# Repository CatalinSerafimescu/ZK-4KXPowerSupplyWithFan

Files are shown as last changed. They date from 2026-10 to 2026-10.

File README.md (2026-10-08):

# ZK-4KX Enhanced Power Supply — temperature-controlled fan

A bench power supply built around the cheap **ZK-4KX buck-boost panel module** (IN 5–30 V, OUT 0.5–30 V,
[datasheet](https://www.laskakit.cz/user/related_files/zk-4kx_english.pdf)), with a 3D-printed case and a small
add-on board that runs a cooling fan **only when the module gets warm**, faster as it gets hotter.
Everything runs from the same DC input (9 V / 2 A adapter tested, up to ~28 V supported).

| Finished supply | Inside |
|---|---|
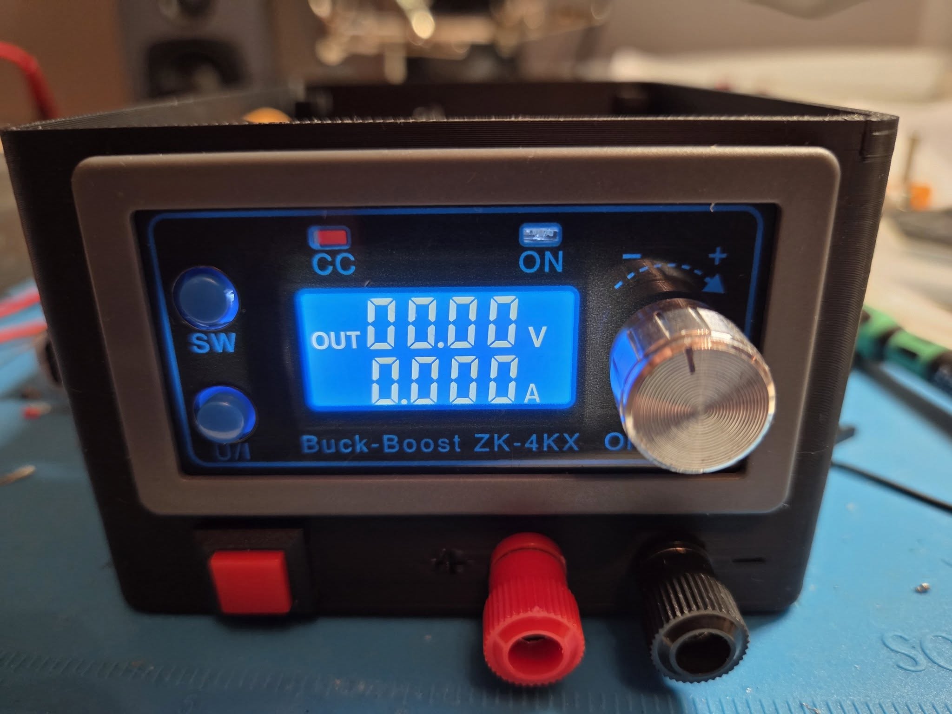
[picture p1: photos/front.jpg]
Front
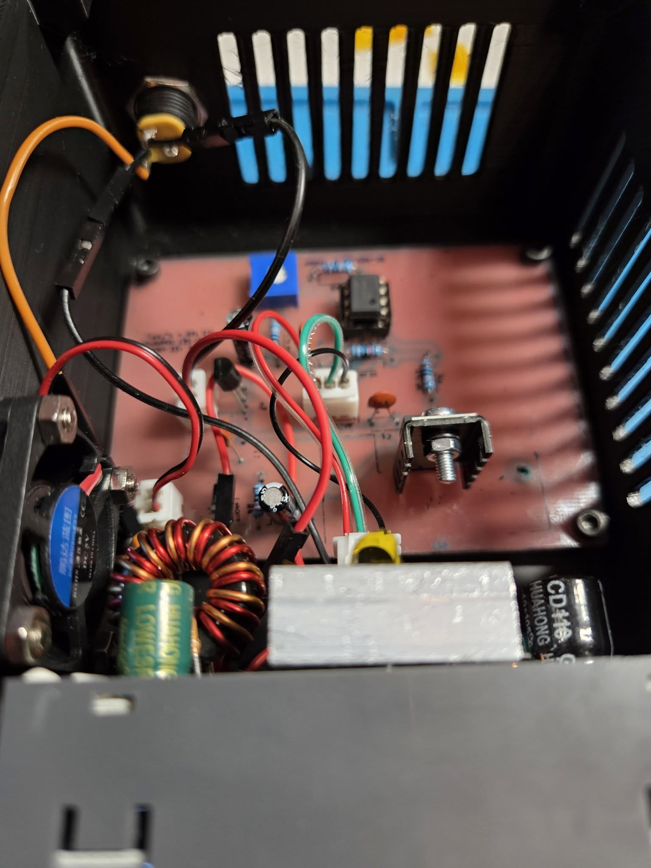
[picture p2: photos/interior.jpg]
Interior
|  |  |

- Single-sided PCB, 90 × 66 mm, designed for **home etching** (toner transfer, no vias, no jumpers) — Gerbers included if you'd rather order it.
- Through-hole parts only: LM35, LM358, LM317, 78L05, one trimmer.
- Fan **off** below a start temperature you set with the trimmer (~15 … 52 °C), full speed ~18 °C above it.
- Fan voltage can never exceed 5 V, whatever the input voltage or faults.
- Printable case, 98 × 128 × 68 mm, magnetic lid, no supports.

**Build guide:** [instruction.md](instruction.md) — parts, etching, assembly, wiring, first power-up, calibration, troubleshooting.

## Downloads

| What | File |
|---|---|
| Bill of materials | [bom.md](bom.md) |
| Schematic | [KiCAD/SursaTensiune_sch.pdf](KiCAD/SursaTensiune_sch.pdf) |
| PCB print for toner transfer (+ solder mask film), A4, print at 100 % | [KiCAD/toner_B.Cu_1to1.pdf](KiCAD/toner_B.Cu_1to1.pdf) |
| Gerbers + drill files for ordering the PCB | [KiCAD/gerber/SursaTensiune_gerbers.zip](KiCAD/gerber/SursaTensiune_gerbers.zip) |
| Assembly BOM in PCBWay's format | [KiCAD/SursaTensiune_BOM_PCBWay.xlsx](KiCAD/SursaTensiune_BOM_PCBWay.xlsx) |
| Enclosure, printable | [Enclosure_base.3mf](mechanical/enclosure/Enclosure_base.3mf), [Enclosure_cover.3mf](mechanical/enclosure/Enclosure_cover.3mf) (print orientation; STL and STEP next to them), [Bambu Studio project for the A1](mechanical/enclosure/Enclosure_A1_project.3mf) — see [enclosure notes](mechanical/enclosure/README.md) |
| Solder-mask jig, printable (optional) | [Mask_jig.stl](mechanical/mask_jig/Mask_jig.stl) — see [jig notes](mechanical/mask_jig/README.md) |
| KiCad 10 project | [KiCAD/](KiCAD/) — see [PCB_info.md](KiCAD/PCB_info.md) |

## Build photos

| Design | | |
|---|---|---|
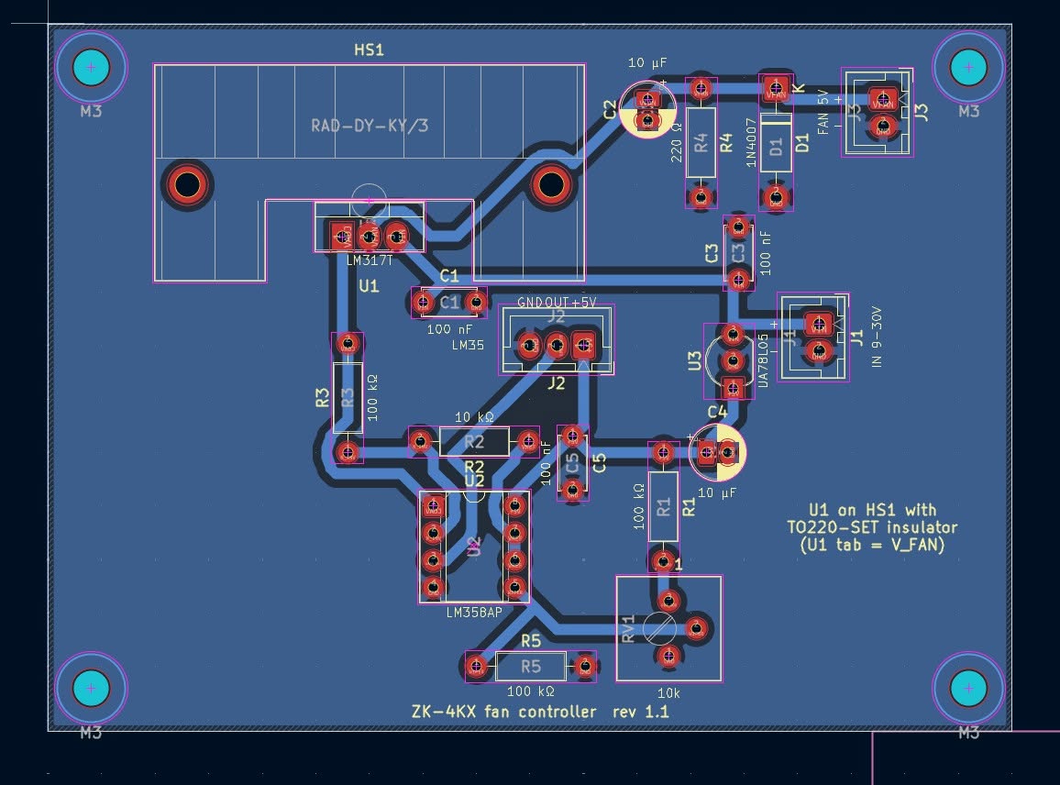
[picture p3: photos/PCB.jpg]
PCB layout
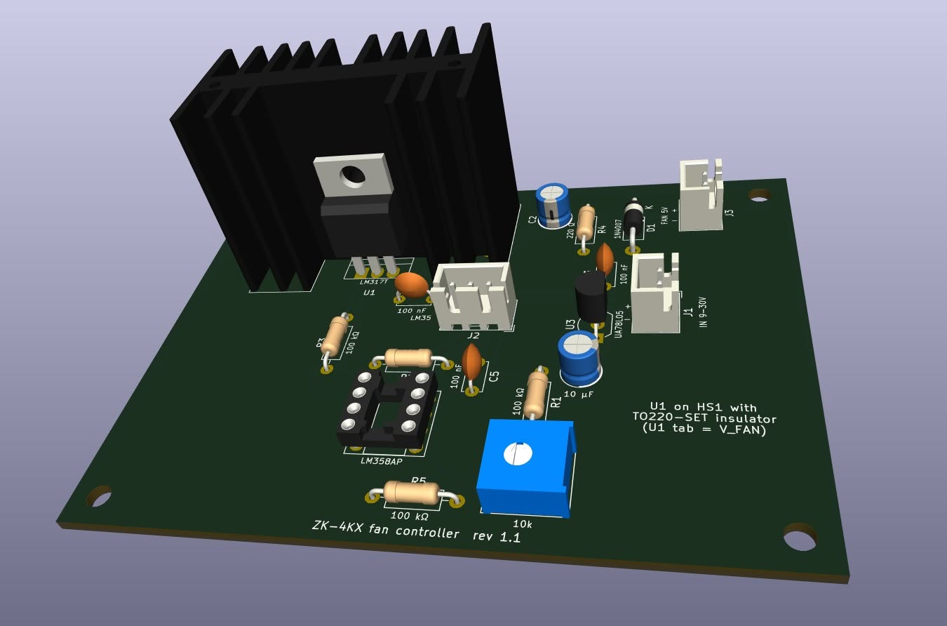
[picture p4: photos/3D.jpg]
3D view
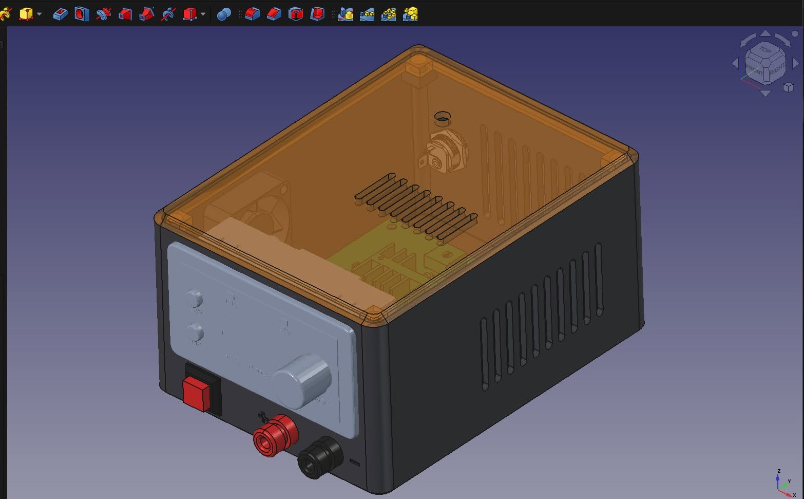
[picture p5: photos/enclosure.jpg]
Enclosure model
|  |  |  |
| PCB layout (KiCad) | 3D view | Enclosure (FreeCAD) |

| Making the board | | |
|---|---|---|
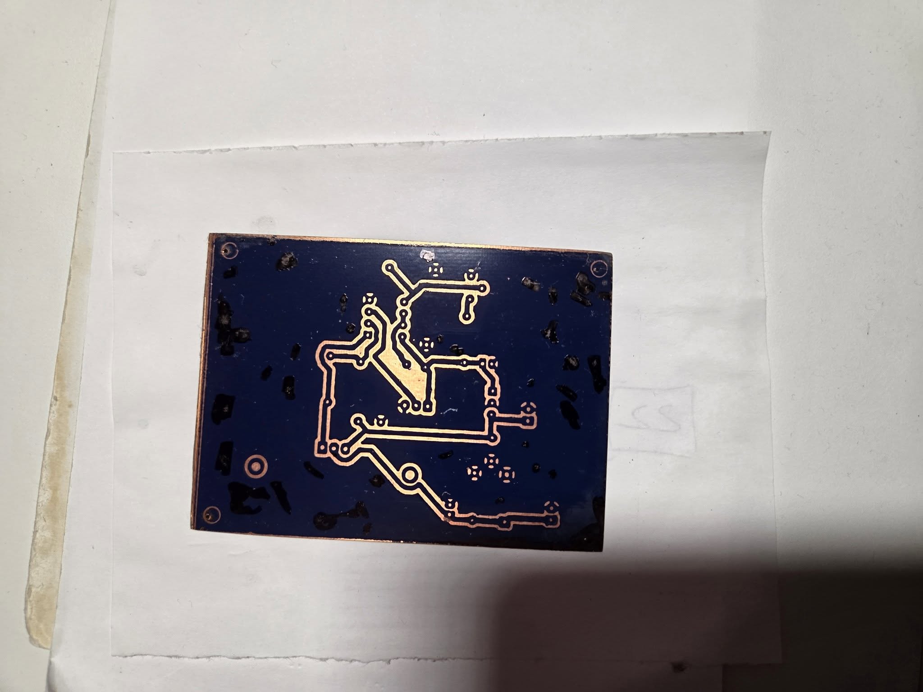
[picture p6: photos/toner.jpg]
Toner transfer
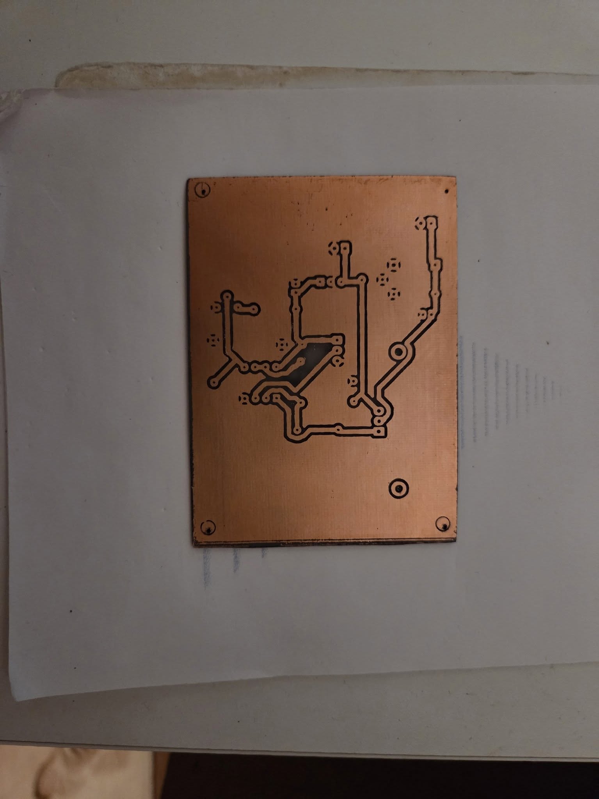
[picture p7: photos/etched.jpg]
Etched
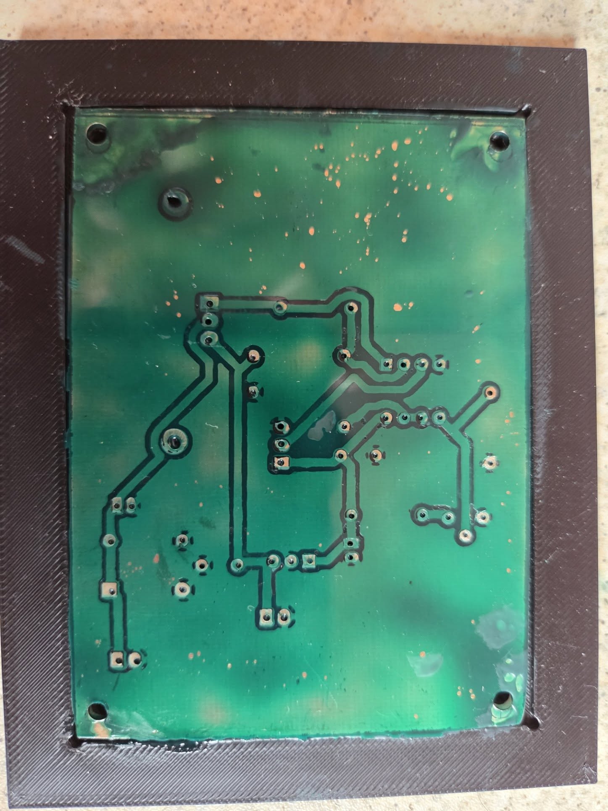
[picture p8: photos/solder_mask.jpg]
Solder mask
|  |  |  |
| Toner transferred | Etched | UV solder mask, board in the printed jig |
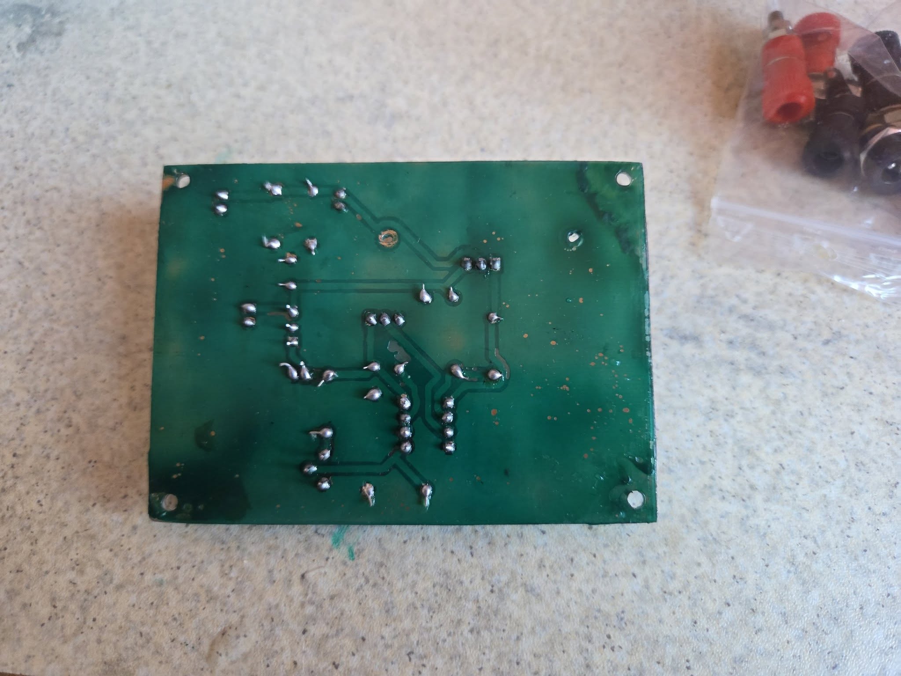
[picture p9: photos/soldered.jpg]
Soldered, bottom
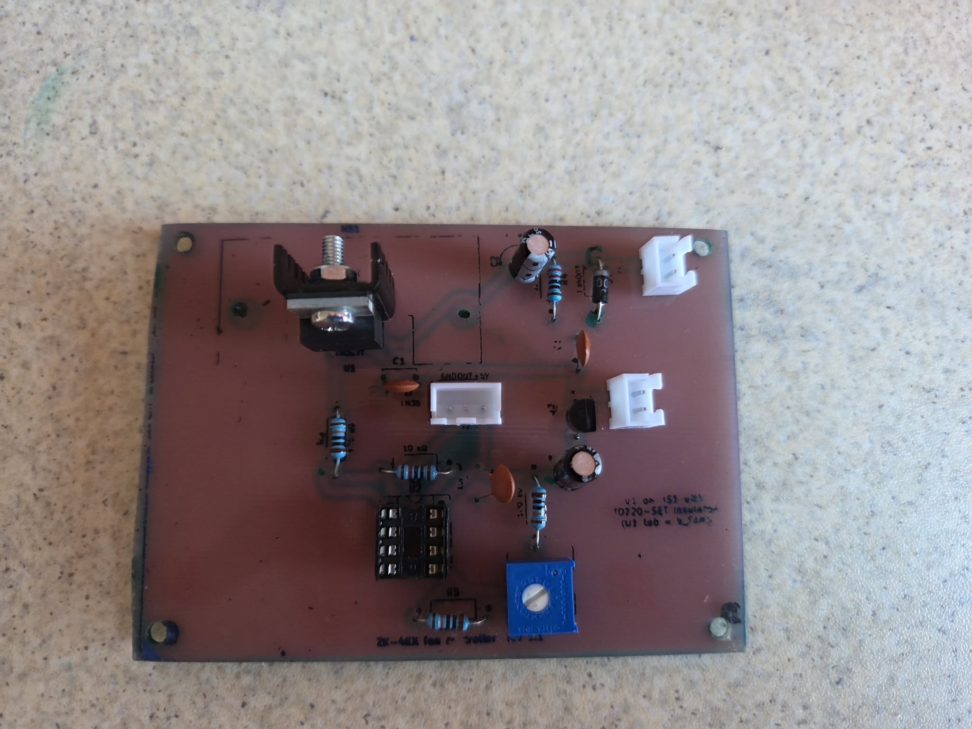
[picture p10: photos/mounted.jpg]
Assembled
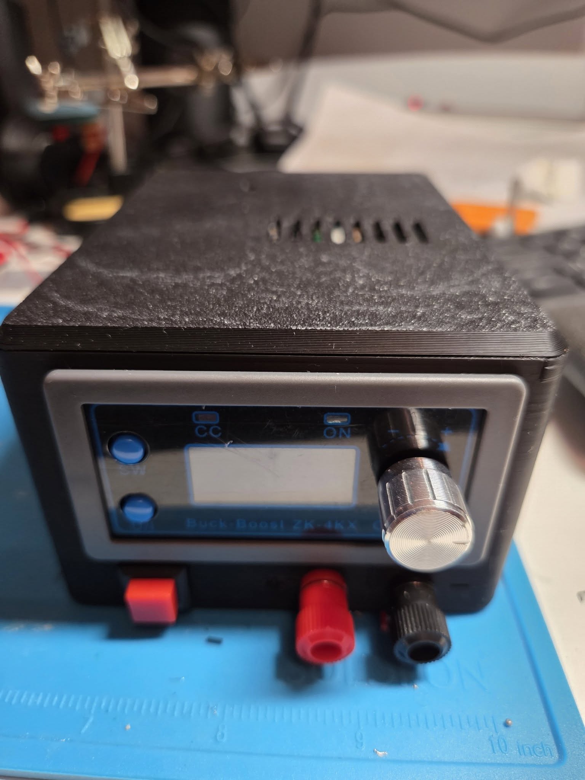
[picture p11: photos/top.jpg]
Top
|  |  |  |
| Soldered (bottom) | Assembled board | Closed case, vents on top |

## How it works

| Block | Parts | Function |
|---|---|---|
| 5 V aux | U3 78L05, C3, C4, C5 | Supplies U2 and the LM35 |
| Start temperature | R1, RV1, R5, U2B | V_REF = 0 … 0.42 V, buffered |
| Amplifier | U4 LM35, U2A, R2, R3 | V_ADJ = 11·V_LM35 − 10·V_REF (clamped 0 … ~3.5 V by the 5 V supply) |
| Fan supply | U1 LM317, C1, C2, R4, D1 | V_FAN = V_ADJ + 1.25 V → 1.25 V (off) … 4.75 V (full) |

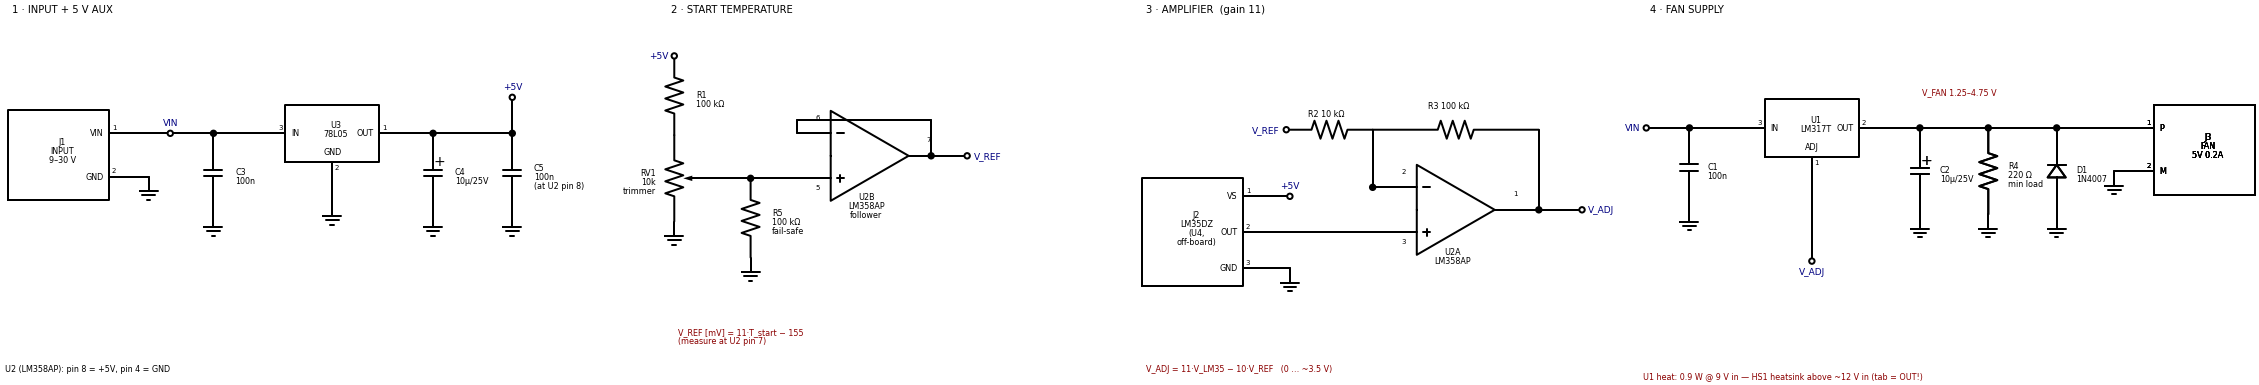
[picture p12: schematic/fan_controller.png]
Schematic


- Fan: Raspberry Pi type 30×30×10 mm, 5 V / 0.2 A, 2-wire. The LM35 sits on the ZK-4KX heatsink.
- Fan starts (≈ 2.8 V, measured) at **T_start**, reaches full speed at **T_start + ~18 °C**.
- T_start range with RV1: **~15 … 52 °C**.
- **Calibration:** measure U2 pin 7 → **V_REF [mV] = 11 · T_start − 155** (e.g. 285 mV → 40 °C).
- Narrower ramp (~9.5 °C): R2 = 5.1 kΩ.
- Fail-safes: pot wiper open → fan runs from ~17 °C (R5); LM35 disconnected → fan full speed.
- U1 dissipation: 0.9 W @ 9 V in, 5.3 W @ 30 V in (HS1 + insulating kit; tab = OUT).
- Simulated in both ngspice and LTspice (nominal, trimmer extremes, input sweep, power-up, open wiper/sensor,
  op-amp offset worst cases) — see [simulation/README.md](simulation/README.md).

## Repository layout

| Path | Content |
|---|---|
| `bom.py` → `bom.md` | BOM, single source of truth. Run `python bom.py`. |
| `instruction.md` | Build guide |
| `schematic/` | Schematic image (schemdraw, `gen_schematic.py`), labels from `bom.py` |
| `KiCAD/` | KiCad 10 project, generator scripts (`gen/`), print PDF, Gerbers. See `KiCAD/PCB_info.md`. |
| `simulation/` | Same scenarios in ngspice 46 and LTspice 26 |
| `mechanical/` | Enclosure and solder-mask jig (FreeCAD scripts, STEP, STL, 3MF), part models used for fit checks. See `mechanical/README.md`. |
| `photos/` | Build photos |

## Credits and third-party files

These files are not mine and keep their original terms (they are **not** covered by this project's licenses):

- `mechanical/stl/ZK-4KX Buck Boost Converter.STL` — by Legacy_Micro,
  [Printables 401707](https://www.printables.com/model/401707-basic-model-zk-4kx-buck-boost-converter), CC0.
- `mechanical/button/DS-431_square_push_button_red.step` — from
  [GrabCAD](https://grabcad.com/cads/files/da40e36f2500ba5d71d7cf6f930e5d73/original.step).
- `mechanical/fan/Fan_30x30x10_5V_2pin.step` — modified from A. Kirchner's 30×30×8 fan model,
  [GrabCAD](https://grabcad.com/library/fan-30x30x8mm-5v-2-pin-1).
- `mechanical/dc_jack/DC_jack_5.5x2.1_panel_10A.step` (+ 2 renders) — from
  [GrabCAD](https://grabcad.com/library/power-jack-socket-5-5-x-2-1-mm-10a-dc-1).
- `mechanical/heatsink/*.jpg` — TME product images of the Stonecold RAD-DY-KY heatsink.
- ZK-4KX datasheet and heatsink datasheet are linked, not included.

**Not included** (licences don't allow redistribution) — download them and save under these names if you need them:

| File | What | Where to get it | Needed for |
|---|---|---|---|
| `KiCAD/vendor/3386P-1-103LF.stp` | Bourns 3386P trimmer 3D model | [SamacSys / Component Search Engine](https://componentsearchengine.com) | RV1 3D body in KiCad |
| `mechanical/trimmer/3386P-1-103LF.stp` | same model (copy) | as above | reference only |
| `mechanical/banana/930176100.stp` | Hirschmann 930176100 banana socket | [SamacSys / Component Search Engine](https://componentsearchengine.com) | `mechanical/enclosure/assembly.py` |
| `simulation/vendor/onsemi_LM358.mod` | onsemi LM358 SPICE model | [onsemi models](https://onsemi.com/support/design-resources/models?rpn=LM358) | `run_sim.py --vendor` |
| `simulation/vendor/LT317A.sub` | ADI LT317A SPICE model | bundled with LTspice (`lib.zip` → `lib/sub/LT317A.sub`) | `run_sim.py --vendor` |

Everything else (schematic, PCB, Gerbers, enclosure, behavioral simulations) works without them.

## Support

If this project saved you some time, you can buy me a coffee (via PayPal):

<a href="https://www.paypal.com/donate/?hosted_button_id=YSV46KQ6EUAEE">Buy me a coffee</a>

## License

Copyright © 2026 Catalin Serafimescu. See [LICENSE](LICENSE):

- Hardware (KiCad project, Gerbers, enclosure and jig) — [CERN-OHL-S-2.0](LICENSES/CERN-OHL-S-2.0.txt)
- Software (Python scripts, SPICE files) — [MIT](LICENSES/MIT.txt)
- Documentation and images — [CC BY-SA 4.0](LICENSES/CC-BY-SA-4.0.txt)

Mains is not involved, but you are working with up to 30 V / 4 A — build and use at your own risk.

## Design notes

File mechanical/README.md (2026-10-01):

# Mechanical files

| File | What |
|---|---|
| Heatsink datasheet | Stonecold RAD-DY-KY profile drawing (40×20 mm, 4 mm base, pins at 34 mm, M3, 6.9 K/W for L = 30 mm) — not included, see [TME](https://www.tme.eu/en/katalog/?search=RAD-DY-KY%2F3) |
| `heatsink/RAD-DY-KY.jpg`, `RAD-DY-KY_top.jpg` | TME photo and profile — source for the KiCad footprint (`../KiCAD/gen/gen_heatsink.py`) |
| `stl/ZK-4KX Buck Boost Converter.STL` | ZK-4KX panel module, 79 × 54 × 42.5 mm — by Legacy_Micro, [Printables 401707](https://www.printables.com/model/401707-basic-model-zk-4kx-buck-boost-converter), CC0 |
| `pcb/SursaTensiune_board.step` | Whole fan-controller board with all parts, **including the heatsink** (KiCad export, solids — best for FreeCAD) |
| `pcb/SursaTensiune_board.stl` | Same board as a mesh — 90 × 66 × 39.7 mm |
| `trimmer/3386P-1-103LF.stp` | Bourns 3386P trimmer — **not included** (SamacSys licence: no redistribution). Download from [SamacSys / Component Search Engine](https://componentsearchengine.com), part 3386P-1-103LF. |
| `banana/930176100.stp` | 4 mm banana panel socket (Hirschmann 930176100), ≈ 33 × 15 × 10 mm — **not included** (SamacSys licence: no redistribution). Download from [SamacSys / Component Search Engine](https://componentsearchengine.com); needed by `enclosure/assembly.py`. Stand-in for J6/J7 — the Sigmanortec sockets may differ slightly, measure. |
| `dc_jack/DC_jack_5.5x2.1_panel_10A.step` (+ 2 renders) | Panel-mount DC jack 5.5×2.1 mm, 10 A — the one on the case (J5). ≈ 14 × 24 × 20 mm, threaded body + nut, 3 solder tabs. From [GrabCAD](https://grabcad.com/library/power-jack-socket-5-5-x-2-1-mm-10a-dc-1). |
| `button/DS-431_square_push_button_red.step` | Power switch SW1: DS-431 latching push switch, 14 × 14 mm rim, 11.5 × 10.8 mm body with snap clips, 20 mm deep incl. the 2 solder tabs |
| `fan/Fan_30x30x10_5V_2pin.step` (+ `.png`) | 30×30×**10** mm 2-pin 5 V fan (M1). Made in FreeCAD from A. Kirchner's 30×30×8 model ([GrabCAD](https://grabcad.com/library/fan-30x30x8mm-5v-2-pin-1)): frame cut at mid-height, top half raised 2 mm and the gap filled (valid solid, exact planes/cylinders, holes unchanged); rotor unchanged, centred. The original rotor had broken face trims (drawn as an endless tube along the fan axis, reappearing after every STEP round trip), so it was replaced by a clean hub + 7 pitched blades. 203 KB, opens in < 1 s. FreeCAD version: `stl/Fan10.FCStd`. |

The fan mount STL that came with the ZK-4KX model is not used.

Board exports are regenerated with `kicad-cli pcb export step|stl --subst-models` after PCB changes.

KiCad cannot use STL as a 3D model (STEP/VRML only); the fan and ZK-4KX are off-board, so these models are
for the enclosure design. Heatsink 3D: `../KiCAD/SursaTensiune.3dshapes/RAD-DY-KY-3.step` — black solid with rounded fins, pin grooves and the
M3 hole, built in FreeCAD by `../KiCAD/gen/gen_heatsink_step.py` (run it inside the FreeCAD GUI to keep the colours).
Enclosure: see [`enclosure/`](enclosure/README.md). Solder-mask jig (holds the PCB flush under the mask film):
[`mask_jig/`](mask_jig/README.md).

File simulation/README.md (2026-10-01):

# Simulation — fan temperature controller

The same 11 scenarios, run in two simulators:

| Folder | Simulator | Results |
|---|---|---|
| [`ngspice/`](ngspice/README.md) | ngspice 46 (`ngspice_con.exe -b`) | [RESULTS.md](ngspice/results/RESULTS.md) |
| [`ltspice/`](ltspice/README.md) | LTspice 26 (`LTspice.exe -b`) | [RESULTS.md](ltspice/results/RESULTS.md), vendor models: [RESULTS.md](ltspice/results_vendor/RESULTS.md) |

[`scenarios.py`](scenarios.py) is shared: stimuli, parameters and pass/fail assertions are defined once.
Each folder has its own netlist template and `models.lib` (identical behavioral models today).
[`vendor/`](vendor/README.md) holds manufacturer models (onsemi LM358, ADI LT317A), used by `ltspice/run_sim.py --vendor`.

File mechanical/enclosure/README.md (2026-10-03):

# Enclosure — 3D-printable case

Parametric FreeCAD script: [`gen_enclosure.py`](gen_enclosure.py) (all dimensions at the top).
[`assembly.py`](assembly.py) places the real part models (ZK-4KX, board, fan, banana sockets, power switch, DC jack) for checking;
the result is saved as [`Enclosure_assembly.FCStd`](Enclosure_assembly.FCStd).

Outside **98 W × 128 D × 68 H mm**. Two printed parts. The `.3mf` files are already in print orientation (cover flipped,
both on the bed); the `.stl` files are in assembly position.

**Bambu Studio project:** [`Enclosure_A1_project.3mf`](Enclosure_A1_project.3mf) — Bambu Lab A1, 0.4 nozzle,
0.20mm Standard, Bambu PLA Basic, no supports; plate 1 = base (≈ 2 h 45 min), plate 2 = cover (≈ 45 min).
Made from the two `.3mf` files with the Bambu Studio CLI, using the system presets with their `inherits` chains
flattened first (the CLI doesn't resolve them and falls back to a 200 × 200 bed); then split into two plates
and renamed by hand. The plain `.3mf` files open in Bambu Studio with a "geometry only" notice — expected for
3MFs not made by Bambu Studio.

| Part | What | Print |
|---|---|---|
| `Enclosure_base` (.step / .stl / .3mf) | Open box: floor + all 4 walls, board standoffs, 4 corner magnet bosses | Floor down, no slicer supports (built-in breakaway pane in the ZK-4KX cutout, see below) |
| `Enclosure_cover` (.step / .stl / .3mf) | Top only (the chamfered cap, split at Z 65): lip inside the walls, 4 corner magnet blocks | **Upside down** (top on the bed), no supports |

Style: rounded vertical corners (R6), 45° chamfer on the top edges (3 mm), 1.2 mm chamfer on the bottom edges
(bed adhesion / elephant foot). Front and rear panels can be printed in a second colour.

## Layout
- **Front:** ZK-4KX on top (cutout 77.4 × 39.6, 6 mm wider than the datasheet so the side clips pass, panel thinned to **1.3 mm** around it — the clips grip 1.4 mm behind
  the bezel). **Below it, one row:** power switch SW1 (DS-431, 12.7 × 11.0 mm hole) on the left, then the banana
  sockets side by side, 19.05 mm apart (fits dual banana plugs), red **+** left, black **−** right (engraved beside them).
  Output leads leave the middle of the front, not the side — fine for right- and left-handed use.
- **Rear:** DC jack Ø12.2 (M12 body) on the left, labelled "9-30V"; exhaust slots.
- **Left side:** fan 30×30×10 on the full 2.4 mm wall (Ø28.5 grille, 4× Ø3.4 holes at 24 mm). Its axis is 11 mm
  behind the ZK-4KX rear heatsink centre, so that heatsink sits under the **blades** (an axial fan blows almost nothing
  behind its Ø17 hub) and the jet (Y 24–54) also reaches the front of the board heatsink (Y 47–67). Air then leaves
  through the right-side, rear and top vents — the board heatsink's fins run front-to-back, along that path.
- **Right side:** exhaust slots.
- **Top (cover):** vents above the board heatsink, **Ø5 hole above trimmer RV1** (set the start temperature with the lid on).
- **Inside:** fan board on 4 × 6 mm standoffs behind the ZK-4KX, rotated 180°, 1.5 mm from the left wall — its front
  edge runs under the fan (the parts there, J3 and C2, stay below it), J3 right under the fan.

## Assembly
| Joint | Hardware |
|---|---|
| Fan board → base | 4× **M3×10** from the top, M3 nuts pushed into the hex pockets under the floor |
| Cover → base | 4 pairs of **Ø5×3 neodymium magnets** (comp_193) in the corners; the lip inside the walls locates it |
| Fan → base | 4× **M3×16** + nuts through the 2.4 mm left wall |
| ZK-4KX | snaps into the front cutout from the front |
| Banana sockets, DC jack | their own nuts, from inside (lid off) |
| Power switch SW1 | snaps in from the front (wire it before, or push it out from inside to rewire) |

Order: ZK-4KX, banana sockets, switch, DC jack into the base → wire them → board on the standoffs → plug J1/J2 →
fan on the left wall → plug J3 → put the cover on (it snaps down on the magnets, lift to open). Stick-on rubber feet
recommended.

**Magnets:** pockets are Ø5.3 × 3.3 deep (0.3 mm glue room; the magnet ends 0.3 mm below the face). Glue them with
a drop of CA. Mind the polarity: snap each pair together, mark the two touching faces with a
marker, pull them apart, and glue each one with the marked face out (base magnet in its boss, partner in the cover
block above it). Boss tops sit 0.2 mm below the cover blocks, so the cover rests on
the wall rim, not on the magnets.

## Fit check (done in FreeCAD with the real models)
- No collisions between the base/cover and the board, fan, banana sockets, power switch or DC jack. The only
  overlaps are the switch's snap clips (0.6 mm wedges behind the panel edge — that is how it holds) and the LM317's
  uncut 3D-model leads (see below).
- ZK-4KX (STL mesh) clear of all walls and of the fan (closest ZK part 2.9 mm from the fan face — the fan follows
  the ZK-4KX heatsink height). Banana sockets ≥ 4.5 mm and the switch ≥ 2.7 mm below the ZK-4KX body.
- Board front edge under the fan: tallest part there (C2, J3) tops out at Z 17, fan bottom at Z 26.5.
- Cover lip (Z 61.5–65) and the corner magnet bosses (Z ≥ 49, 8 × 8 mm in the corners): clear of the ZK-4KX
  (body X 14.5–85.5, top Z 60.5; its clips reach X 11–89 only at Z 35–47), of the fan (top Z 57.8) and of the
  board (Y 43–109). No overlap between base and cover.
- Trimmer hole in the lid centred on RV1's adjuster (checked on the board STEP).
- Under the board: 6 mm standoffs. **Trim all leads to ≤ 3 mm** below the PCB (the KiCad LM317 model shows uncut
  leads that would touch the floor).

## Check before printing
- Banana sockets: the model is a stand-in (Hirschmann 930176100, M6) — measure your Sigmanortec sockets' thread.
- Power switch: hole 12.7 × 11.0 mm (DS-431 model 11.7, +1 mm after the first fit test; body 11.5 × 10.8, clips on the 11.5 sides);
  change `SW_CUT` if needed. The front panel is 2.4 mm there; the clips suit 1–3 mm panels.
- ZK-4KX clip grip (1.4 mm) is from the STL model; the panel is 1.3 mm there — if the clips don't catch, reduce `ZK_PANEL`.
- The 77 mm top edge of the ZK-4KX cutout is a print bridge. The base carries its own **breakaway window pane**
  there: a 0.8 mm plate flush with the front face, standing on 7 posts (0.8 × 0.6 × 0.6 mm) on the cutout's bottom
  edge, held by 3 sprues per side across a 0.5 mm gap, its top one layer (0.2 mm) below the edge. Tuned for
  **0.2 mm layers / 0.4 mm nozzle** (cutout edges, pane and sprues on the 0.2 mm grid; cutout Z 21.2 / 60.8).
  Slicer supports off. After printing, push the pane out from inside and trim the sprue nubs on the side edges
  flush (the ZK-4KX clips run along those edges). Other layer heights: set `PANE_GAP_Z` to one layer and keep the
  cutout edges on the layer grid.

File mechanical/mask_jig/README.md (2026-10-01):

# Solder-mask jig

`Mask_jig.step` / `.stl`, made by `gen_mask_jig.py` (run in the FreeCAD GUI). 110.8 × 86.8 × 4.4 mm, print
floor-down, no supports.

- **Pocket** 90.8 × 66.8 mm (0.4 mm per side around the 90 × 66 board), **1.4 mm deep**: a 1.5–1.6 mm board sits
  0.1–0.2 mm proud, so the film is pressed onto the board and then lies flat on the 10 mm frame. If your board
  is thinner than 1.4 mm, put a paper shim under it.
- **4 × Ø3.2 through holes** at the board's mounting holes (4 mm in from each corner) for registration pins —
  Ø3 drill-bit shanks or M3 screws pushed up from below.
- Corner reliefs (square board corners in an FDM pocket) and 2 × Ø12 holes to push the board out from below.

## Use (UV solder mask)
1. Etched board **drilled**, cleaned, copper side up in the pocket. Pins up through the mounting holes.
2. Film: the two B.Mask copies from page 3 of `KiCAD/toner_B.Cu_1to1.pdf`, stacked, **toner side down**. Punch/drill
   Ø3.2 through the 4 black corner dots (the mounting-hole openings) with the stack taped together.
   The mounting holes are symmetric, so the pins alone don't fix the orientation: check the two big HS1 dots and
   the pad rows line up with the board before the paste goes on.
3. Paste on the board, film down over the pins, squeegee from the centre outwards (excess goes into the gap and
   onto the frame). Tape the film edges to the frame.
4. Pull the pins out **downwards**, lay a sheet of glass on top for even pressure, expose. Ordinary picture-frame
   glass passes 395–405 nm LEDs well but cuts a lot at 365 nm — expose longer, or skip the glass with a 365 nm lamp.
5. Paste squeezed onto the frame cures there too: cover the frame with one layer of packing tape before step 3 and
   peel it off afterwards, so the frame stays flat for the next board.

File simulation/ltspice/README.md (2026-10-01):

# Simulation — LTspice port

Port of the [ngspice simulation](../ngspice/README.md): same circuit, same behavioral models, same scenarios and assertions ([`../scenarios.py`](../scenarios.py)).
Optionally runs with **vendor models** for U1 (LM317) and U2 (LM358) instead of the behavioral ones.

## Prerequisites
- LTspice 26 at `%LOCALAPPDATA%\Programs\ADI\LTspice\LTspice.exe`
- Python 3 with `numpy`, `pandas`, `matplotlib`

## Running
```bash
cd simulation/ltspice
python run_sim.py --all            # behavioral models → results/RESULTS.md
python run_sim.py --all --vendor   # onsemi LM358 + ADI LT317A → results_vendor/RESULTS.md
python run_sim.py A_nominal_40C    # one scenario
python run_sim.py --list
```
Per scenario, `results[_vendor]/<name>/`: `sim.net` (rendered netlist), `sim.log`, `out.csv`, `plot.png`, `summary.txt`.
The `.raw` file is read and then deleted; open `sim.net` in LTspice and press Run to get the waveforms interactively.

## Differences from the ngspice version
- `fan_ctrl.net.tmpl`: the ngspice `.control` block is replaced by `.save` + a plain `.dc` / `.tran` directive.
- `.options numdgt=16 plotwinsize=0`: double-precision, uncompressed `.raw`, so crossings are interpolated on the same grid as ngspice.
- `models.lib` is a verbatim copy — the B-source syntax (`V=`, `I=`, `min`/`max`) and `params:` subcircuits are accepted by both simulators.
- C2 has 1 Ω ESR (`Rser=1`, aluminium electrolytic); the ngspice netlist has an ideal C2. See the stability note below.
- Plots reuse `plot()` from `../ngspice/run_sim.py`.

Behavioral DC sweeps are identical to ngspice (V_fan and I_out differ by < 1 µV / 1 µA at every point). Transients differ slightly around the 0.1 ms input ramp (time-step control and C2 ESR): E power-up peak 4.74 V vs 4.82 V, G cold peak 1.68 V vs 1.62 V; all well inside the limits.

## Vendor models (`--vendor`)
[`models_vendor.lib`](models_vendor.lib) wraps the files in [`../vendor/`](../vendor/README.md) with the behavioral pin order and `VOS`/`IB` params, so the template only swaps subcircuit names:
- **U2 LM358** → onsemi LM358 (transistor level). `VOS`/`IB` add the difference to the model's built-in −0.42 mV / 9.6 nA, so H/J/K keep their worst-case meaning.
- **U1 LM317** → ADI LT317A (bundled with LTspice, encrypted).

How it is simulated: with these models an operating point is only easy to find with everything unpowered, and `.dc` sweeps stall for minutes. So each `.dc` scenario becomes a quasi-static `.tran`: V_in steps up from 0 at 1 ms, settles, then from 10 ms the swept source ramps at 1 °C/ms (or 1 V/ms). Halving the ramp rate gives identical results. `method=gear` is used because trap stalls in the 0→30 V power-up (F). All 11 run in ~23 s.

### Findings
| Scenario | Behavioral | Vendor | Why |
|---|---|---|---|
| A fan start (40 °C setting) | 40.1 °C | 40.0 °C | — |
| A fan "off" at 25 °C | 1.25 V | 1.47 V | U2A can't pull ADJ fully to 0 V while sinking the LT317A ADJ current |
| Fan maximum | 4.74 V | 4.90 V | real LM358 swings higher than the V_cc − 1.5 V behavioral limit |
| **B** pot at minimum | 14.7 °C | **22.7 °C — FAIL (≤ 15 °C)** | U2B follower must *sink* ~10 µA from R2 near 0 V; a class-B LM358 can't (datasheet: 12 µA min at V_O = 200 mV), so V_ref sits at 40…140 mV instead of 5 mV |
| **H** wiper open, 250 nA bias | 16.6 °C | **23.0 °C — FAIL (≤ 20 °C)** | same V_ref floor; fail-safe still turns the fan on, just later |
| LM317 dissipation @ 30 V | 5.33 W | 5.48 W | LT317A input/quiescent current |

**Stability:** with an ideal (0 Ω ESR) C2, the LT317A + onsemi LM358 driving ADJ oscillates at mid-range (V_fan 0.8…3.2 V, 2.3 A current-limit bursts). 0.2 Ω ESR is already stable, and the BOM's aluminium electrolytic has far more — **don't replace C2 with a ceramic.**

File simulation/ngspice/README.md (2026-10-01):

# Simulation — fan temperature controller

DC sweeps and transients (ngspice 46) verifying every operating regime and fault before PCB.

## Prerequisites
- ngspice 46 at `E:\Catalin\Work\Electronics\NGSpice_46\bin\ngspice_con.exe` (console build; `ngspice.exe` opens a GUI)
- Python 3 with `numpy`, `pandas`, `matplotlib`

## Running
```bash
cd simulation/ngspice
python run_sim.py --all          # all scenarios → results/RESULTS.md
python run_sim.py A_nominal_40C  # one scenario
python run_sim.py --list
```
Per scenario, `results/<name>/`: `sim.cir` (rendered netlist), `out.csv`, `ngspice.log`, `plot.png`, `summary.txt`.

## Scenarios
Defined in [`../scenarios.py`](../scenarios.py), shared with the [LTspice port](../ltspice/README.md).

| Name | What it checks |
|---|---|
| `A_nominal_40C` | Temperature sweep, pot set for 40 °C: off at 25 °C, start at 40 ± 1 °C, full ≥ 62 °C, V_fan ≤ 5.25 V |
| `B_pot_min` / `C_pot_max` | Adjustment range of the start temperature (≈ 12 / 49 °C) |
| `D_vin_sweep_hot` | V_in 6–30 V at 70 °C: V_fan constant; LM317 dissipation at 9 V and 30 V |
| `E/F_powerup_*_hot` | Power-up at 9 V / 30 V when hot: no overshoot above 5.25 V |
| `G_powerup_9V_cold` | Power-up when cold: fan does not kick on |
| `H_wiper_open` | Fault: pot wiper open with worst-case LM358 bias (250 nA) → fan still runs (fail-safe) |
| `I_sensor_open` | Fault: LM35 disconnected → fan full speed (fail-safe) |
| `J/K_offset_worst_*` | LM358 offset ±7 mV on both halves in opposite directions → start shift ≤ 1.5 °C (uncalibrated) |

## Key nodes
| Node | Meaning |
|---|---|
| `V(t)` | Stimulus: voltage = temperature in °C |
| `V(n_vref)` | U2B output (pin 7) — calibration point |
| `V(n_adj)` | U2A output (pin 1) = LM317 ADJ |
| `V(vfan)` | Fan voltage |
| `I(V_i317)` | LM317 output current (fan + R4) |

## Model notes
All ICs are **behavioral** stand-ins in `models.lib` (no vendor models):
- **LM317** — V_out = V_adj + 1.25 V, 1.7 V dropout, 50 µA ADJ current; input current not modeled, dissipation = (V_in − V_fan) · I_out.
- **78L05** — 5.00 V, 1.7 V dropout, 3 mA quiescent.
- **LM358** — 100 dB, 1 MHz GBW, output 5 mV … V_cc − 1.5 V, params `VOS` and `IB` (bias flows out of the inputs, pulls a floating input high).
  The V_cc − 1.5 V high swing sets the fan maximum (≈ 4.75 V); a real part at light load may swing ~0.2 V higher → ≈ 5.0 V, still in spec.
- **LM35** — 10 mV/°C, needs V_s ≥ 4 V.
- **Fan** — 25 Ω resistor (5 V / 0.2 A). A real brushless fan draws less at 1.25 V ("off") than this model shows.

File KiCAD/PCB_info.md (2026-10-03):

# KiCad project — ZK-4KX fan controller

KiCad 10. Open `SursaTensiune.kicad_pro`.

## Status
- **Schematic** — complete, ERC 0 violations. Generated from `gen/gen_sch.py` + `../bom.py`.
- **PCB** — 90 × 66 mm, **routed single-sided** (B.Cu only, no vias, no jumpers) for home etching (toner transfer),
  GND = copper pour on B.Cu. DRC clean, 0 unconnected. Previews: `board.pdf`, `board_top.png`, `board_bottom.png`,
  `board_3d.png`. **Etching print:** `toner_B.Cu_1to1.pdf`. **Fab files:** `gerber/SursaTensiune_gerbers.zip`;
  assembly BOM for PCBWay `SursaTensiune_BOM_PCBWay.xlsx` (`gen/gen_pcbway_bom.py`, from `bom.py` + PCBWay's template).

## Regenerating
```bash
cd gen
python check.py         # schematic from bom.py → ERC → netlist → PDF → DRC on the existing board
python check.py --pcb   # ALSO rebuilds the PCB placement — refuses while the board is routed (--force)
```
The board is routed, so it is the master now: edit the schematic in KiCad (or keep using `check.py` without
`--pcb`) and use *Tools → Update PCB from Schematic* — footprints are linked to the symbols by UUID.
`gen_pcb.py` still holds the placement (`PLACE`), so an unrouted board can always be rebuilt from it.

Gerbers (Protel extensions, F/B.Cu, F/B.Mask, F.Silkscreen, Edge.Cuts + Excellon PTH/NPTH), zipped into `gerber/`:
```bash
kicad-cli pcb export gerbers --layers F.Cu,B.Cu,F.Mask,B.Mask,F.Silkscreen,Edge.Cuts --subtract-soldermask -o out/ SursaTensiune.kicad_pcb
kicad-cli pcb export drill --format excellon --excellon-separate-th -o out/ SursaTensiune.kicad_pcb
```

## Board vs off-board
Parts with `on_board = no` are in the schematic and BOM but not on the PCB:

| Ref | Part | Connects to |
|---|---|---|
| J5 | DC jack 5.5×2.1 (panel) | VIN/GND → PS1 IN and board **J1** |
| PS1 | ZK-4KX panel module | IN+/IN− from J5; OUT+/OUT− → J6/J7 |
| J6 / J7 | Banana red / black | PS1 OUT+ / OUT− (**not** tied to GND) |
| U4 | LM35DZ on the ZK-4KX rear heatsink (fin root) | board **J2** (1 +5V, 2 OUT, 3 GND) |
| M1 | Fan 5 V 0.2 A | board **J3** (1 +, 2 −) |

## RV1 trimmer (start temperature)
Bourns 3386P 10k on the board (footprint: stock `Potentiometer_Bourns_3386P_Vertical`). Its 3D model is the
SamacSys STEP `vendor/3386P-1-103LF.stp` — **not included** (SamacSys licence: no redistribution). Download it from
[SamacSys / Component Search Engine](https://componentsearchengine.com) (part 3386P-1-103LF) and save it under that name, otherwise KiCad just shows RV1 without a 3D body. Clockwise = hotter.
Place the board so the trimmer is reachable with a screwdriver (and a multimeter probe on U2 pin 7).

## Home-etching rules (toner transfer)
- **Tracks 1.0 mm, clearance 0.5 mm** (net class Default in the project), copper 1 mm from the board edge.
- **Pads enlarged** by `gen_pcb.py` (`toner_pads`): copper ring ≥ 0.5 mm per side; where the pitch is too tight
  (TO-220, XH, 2 mm electrolytics) the pad becomes oval, keeping ≥ 0.6 mm between pads. That is why DRC's
  *footprint differs from library* and *silkscreen clipped by pad* checks are set to ignore.
- **U3 on `TO-92_Inline_Wide`** (2.54 mm pitch instead of 1.27 mm) — room for real pads; splay the leads slightly.
- **No track between IC pins** (1.8 mm pads at 2.54 mm leave 0.74 mm).
- **GND pour:** 0.8 mm clearance, 0.5 mm minimum width, thermal reliefs 0.6 mm gap / 0.8 mm spokes.
- Drills: **0.8 mm** R, C, U2, U3, RV1 · **0.95 / 1.0 mm** J2 / J1, J3 · **1.1 mm** U1, D1 · **2.2 mm** HS1 pins ·
  **3.2 mm** mounting holes.
- Print `toner_B.Cu_1to1.pdf` at **100 % (no "fit to page")**, **not mirrored** — the bottom layer is shown as seen
  from the top, which is what toner transfer needs (the paper goes face-down on the copper). Check the 90 × 66 mm
  outline with a ruler before transferring.
- The PDF is **A4 portrait**, everything at the top of the page (boards 11–77 mm from the top edge, left one at
  11–101 mm, right one at 111–201 mm), so the rest of the sheet can be cut off and reused.
- Page 1 has B.Cu (left) and, next to it, the **F.SilkS mirrored** (right) for toner transfer onto the
  component side (align on the drill holes). Page 2: F.SilkS as seen from the top — assembly reference.
  Page 3: **B.Mask twice** (+ outline), same orientation as B.Cu — black = pad openings, i.e. the film for a
  UV-cured solder mask (opaque pads block the UV, the rest cures). The two copies are cut apart and stacked.
- Page layout: layers plotted with `kicad-cli pcb export pdf --black-and-white` (+ `--mirror` for the silk,
  `--drill-shape-opt 0` for the mask), cropped to the outline ± 1 mm and placed 1:1 with PyMuPDF.

## Layout (single-sided)
Made in `gen/route_trial.py` — 5 rounds, each placement routed with both **Freerouting 2.4.1** and
**KiCadRoutingTools** (`gen/freeroute.py`: B.Cu only; for Freerouting F.Cu is declared a plane layer in the DSN).
HS1/U1 and the mounting holes are fixed (airflow, enclosure). Main ideas:
- Front strip: VFAN runs from U1 under the heatsink to C2 / R4 / D1 / J3 (J3 near the fan); VIN from U1 to C3 / U3 / J1.
- U2 (LM358) is behind R2 (10k): R2 bridges N_INV (pin 2) and VREF (pins 6/7), and VADJ, LM35_OUT and +5V pass
  under its body. LM35_OUT uses the channel between the socket's pin rows.
- C5 and R1 hang off the +5V track; WIPER runs between RV1's GND and POT_TOP pads; R1-2 sits right next to RV1's
  POT_TOP pad and C3 right next to U3's input so no track can split them.
- Op-amp and its resistors are at the back, ≈ 20 mm from HS1 and away from the ZK-4KX heatsink side.
- **GND is only the pour** — routing it as tracks first made both routers wall off other nets.

| Round | Change | Freerouting | KiCadRoutingTools |
|---|---|---|---|
| 1 | first single-sided placement | 3 unconnected | 6 |
| 2 | C5 / R1 below the +5V track, RV1 upright | 2 | 2 |
| 3 | R1 over RV1, C3 moved | 5 | 7 |
| 4 | round 2 + tight pad pairs (R1–RV1, C3–U3) | 3 | 4 |
| 5 | round 4, GND as pour only | 4 | **0** ← used |

The board is the KiCadRoutingTools result of round 5 (166 tracks, all 1.0 mm; a 0.02 mm stub removed).
Freerouting kept failing a few very short hops (U2 pin 6↔7, R1↔RV1, C3↔U3). The trial boards are written to
`trial/` (not in git).

## Check against the real parts before ordering the PCB
- **HS1 RAD-DY-KY/3** — footprint `SursaTensiune.pretty/Heatsink_Stonecold_RAD-DY-KY-3_40x20mm_P34mm` and 3D model
  `SursaTensiune.3dshapes/RAD-DY-KY-3.step` (black solid, fillets, pin grooves — built in FreeCAD by `gen/gen_heatsink_step.py`), footprint by `gen/gen_heatsink.py`, both from the Stonecold RAD-DY-KY datasheet ([TME](https://www.tme.eu/en/katalog/?search=RAD-DY-KY%2F3))
  (40×20 mm profile, 4 mm base, 30 mm tall, 2 PCB pins at 34 mm, M3 thread). Measure and correct in `gen_heatsink.py`:
  pin Ø (hole is 2.2 mm), pin position in the plate (y = −1.5 mm), fin gap on the mounting side (19.6 mm), fin heights.
  U1 sits in the fin gap, tab 0.2 mm (insulating pad) from the mounting face.
  **U1 height:** if the heatsink's M3 hole is at mid-height (15 mm), the TO-220 body must stand ≈ 2 mm above the PCB
  for the tab hole to line up — check before soldering U1.
- **C1/C3/C5** (K104K10X7RF5UH5) — footprint assumes 5.0 mm lead pitch; measure.
- **C2/C4** (EEAGA1E100H, 5 mm Ø) — 2.0 mm pitch footprint.
- **U3 UA78L05** (TO-92 on the wide 2.54 mm footprint) / **U4 LM35** pinouts verified against the KiCad symbols (TO-92: OUT-GND-IN / +Vs-OUT-GND).

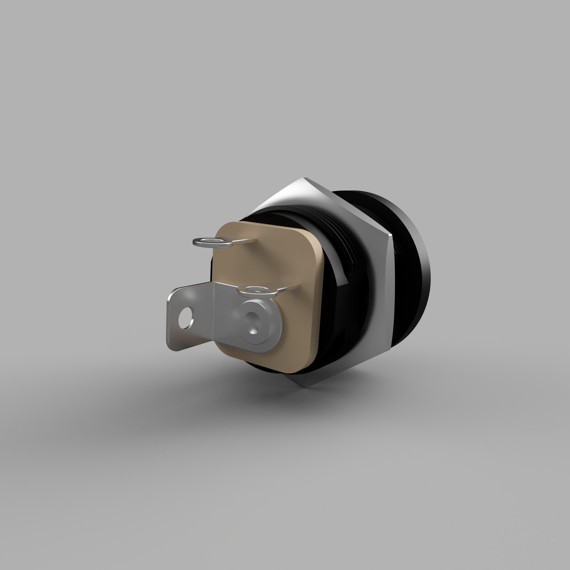
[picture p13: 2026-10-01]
mechanical/dc_jack/DC_jack_5.5x2.1_panel_10A.png

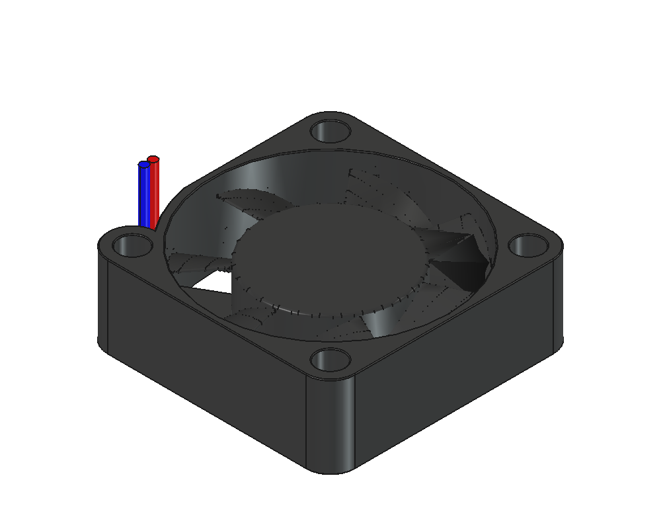
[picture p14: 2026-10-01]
mechanical/fan/Fan_30x30x10_5V_2pin.png

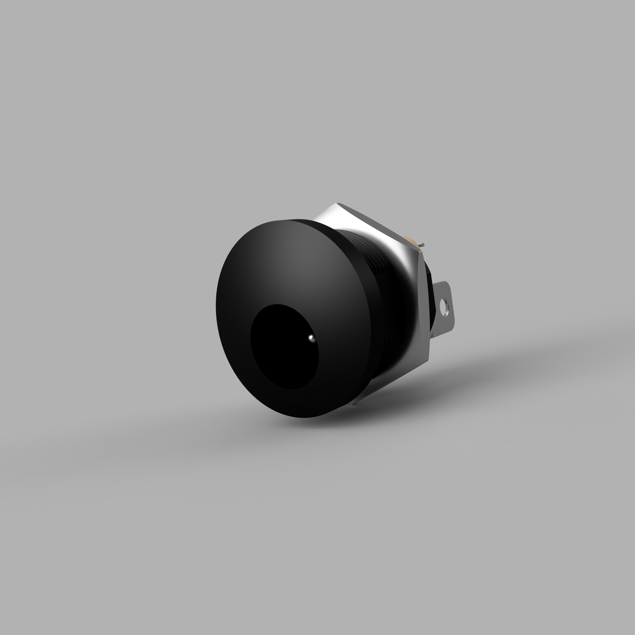
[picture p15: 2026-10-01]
mechanical/dc_jack/DC_jack_5.5x2.1_panel_10A_view2.png

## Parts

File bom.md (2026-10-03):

# BOM — ZK-4KX fan temperature controller

> Generated by `bom.py` — edit that file, then run `python bom.py`.

## Shopping list

**Required:**

- 4× **M3** — Board mounting: M3×10 screws + M3 nuts (any)
- 4× **M3×16** — Fan mounting: M3×16 screws + M3 nuts (any)

**Optional:**

## Full BOM

| Ref | Value | Qty | Description | Part number | Status | Inventory ID | Notes |
|---|---|---|---|---|---|---|---|
| U1 | LM317T | 1 | Adjustable linear regulator, 1.5 A, TO-220, THT | LM317T/NOPB (TI) | ✅ inventory | comp_221 | Fan supply: V_fan = V_adj + 1.25 V. Tab = OUT (insulate from heatsink/chassis). Dissipation 0.9 W @ 9 V in, 5.3 W @ 30 V in (sim D). |
| U2 | LM358AP | 1 | Dual op-amp, single supply, A-grade (Vos ≤ 3 mV), DIP-8, THT | LM358AP (TI) | ✅ inventory | comp_218 | U2A = gain-11 amplifier driving U1 ADJ; U2B = V_ref buffer. Powered from +5 V, so its output (≤ ~3.5 V) caps V_fan at ~4.75 V. |
| U3 | UA78L05 | 1 | 5 V / 100 mA linear regulator, TO-92, THT | UA78L05AILP (TI) — discontinued at TME, 2 in stock | ✅ inventory | comp_219 | Powers U2 + U4 (~2 mA). Pinout (flat face): OUT–GND–IN, reversed vs 7805. Input max ~30 V. |
| U4 | LM35DZ | 1 | Analog temperature sensor, 10 mV/°C, 0–100 °C, TO-92, THT | LM35DZ/NOPB (TI) | ✅ inventory | comp_220 | Off-board via J2, on the ZK-4KX rear heatsink (fin root, flat face down, paste + Kapton); check the heatsink potential and insulate the legs. Leads > ~20 cm: add 75–100 Ω + 1 µF damper at the sensor (datasheet). |
| R1 | 100 kΩ | 1 | Resistor, carbon film, 100 kΩ, 1/4 W, 1 %, axial THT | Rezistor 1/4W 100K 1% | ✅ inventory | comp_117 | Top of threshold divider (R1 : RV1 ≈ 10 : 1 → V_ref 0–0.42 V). |
| R2 | 10 kΩ | 1 | Resistor, carbon film, 10 kΩ, 1/4 W, 1 %, axial THT | Rezistor 1/4W 10K 1% | ✅ inventory | comp_116 | U2A gain resistor Rg. Use 5.1 kΩ for a ~9.5 °C ramp instead of ~18 °C. |
| R3 | 100 kΩ | 1 | Resistor, carbon film, 100 kΩ, 1/4 W, 1 %, axial THT | Rezistor 1/4W 100K 1% | ✅ inventory | comp_117 | U2A feedback resistor Rf (gain = 1 + R3/R2 = 11). |
| R4 | 220 Ω | 1 | Resistor, carbon film, 220 Ω, 1/4 W, 1 %, axial THT | Rezistor 1/4W 220R 1% | ✅ inventory | comp_111 | LM317 minimum load (5.7 mA at 1.25 V, 22 mA / 0.1 W at 4.75 V). |
| R5 | 100 kΩ | 1 | Resistor, carbon film, 100 kΩ, 1/4 W, 1 %, axial THT | Rezistor 1/4W 100K 1% | ✅ inventory | comp_117 | Fail-safe: if the pot wiper loses contact, pulls V_ref low → fan starts at ~17 °C (runs) instead of never (sim H). |
| RV1 | 10k | 1 | Trimmer, Bourns 3386P, 10 kΩ, single-turn, top adjust, THT | 3386P-1-103LF (Bourns) | ✅ inventory | comp_053 | Sets start temperature ~15–52 °C (clockwise = hotter). Calibrate: V_ref(U2 pin 7) [mV] = 11·T_start − 155. |
| C1, C3, C5 | 100 nF | 3 | Capacitor, ceramic X7R, 100 nF, 100 V, THT | K104K10X7RF5UH5 | ✅ inventory | comp_038 | C1 at U1 IN, C3 at U3 IN, C5 at U2 pin 8 — each placed next to its pin. |
| C2, C4 | 10 µF | 2 | Capacitor, aluminium electrolytic, 10 µF, 25 V, radial THT | EEAGA1E100H (Panasonic) | ✅ inventory | comp_037 | C2 at U1 OUT (≤ 5 V), C4 at U3 OUT (5 V). Mind polarity. |
| D1 | 1N4007 | 1 | Diode, rectifier, 1 A, 1000 V, DO-41, THT | 1N4007 | ✅ inventory | comp_062 | Across the fan, cathode to +. Clamps motor spikes. |
| J1, J3 | XH 2-pin | 2 | Connector, JST XH 2.54 mm, 2-pin header + housing + crimps | B2B-XH-A (Kit Conectori XH2.54) | ✅ inventory | comp_156 | J1 = input (wired from J5 / ZK-4KX IN), J3 = fan. Inventory shows the XH kit at qty −5 — check stock. |
| J2 | XH 3-pin | 1 | Connector, JST XH 2.54 mm, 3-pin header + housing + crimps | B3B-XH-A (Kit Conectori XH2.54) | ✅ inventory | comp_156 | J2 = LM35 (1 +5V, 2 OUT, 3 GND). |
| XU2 | DIP-8 socket | 1 | IC socket, DIP-8, 300 mil | Soclu DIP 8 pini | ✅ inventory | comp_235 | For U2 (footprint DIP-8_W7.62mm_Socket). |
| HS1 | RAD-DY-KY/3 | 1 | Heatsink, Stonecold RAD-DY-KY/3, TO-220/TO-3P, 40×20 mm profile, 30 mm tall, 2 PCB pins @ 34 mm, M3 thread, 6.9 K/W | RAD-DY-KY/3 (Stonecold, TME) | ✅ inventory | comp_224 | U1 up to 5.3 W @ 30 V in → Tj ≈ Ta + 5.3·(6.9 + 3 + ~1) ≈ Ta + 58 °C. Stands upright on its 2 solder pins; U1 sits in the fin gap, screwed to the M3 thread. |
| — | TO220-SET | 1 | TO-220 insulating mounting set (pad + bushing), Stonecold | TO220-SET (Stonecold) — alt: Fischer MST 220 (comp_222) | ✅ inventory | comp_223 | Required: U1 tab = V_fan, heatsink must be isolated. Add M3 screw + nut if not in the set. |
| H1, H2, H3, H4 | M3 | 4 | Board mounting: M3×10 screws + M3 nuts | any | 🛒 buy |  | Into the 6 mm standoffs printed in the enclosure base; nuts in the hex pockets under the floor. |
| — | Kapton tape | 1 | Kapton tape 12 mm | Banda Kapton 12mm | ✅ inventory | comp_147 | Fix LM35 to the ZK-4KX rear heatsink. |
| PS1 | ZK-4KX | 1 | Buck-boost CC/CV panel module, 5–30 V in, 0.5–30 V / 4 A out, 79×43×26 mm (cutout 71×39) | ZK-4KX (boxed panel version) | ✅ have |  | 35 W natural / 50 W with active cooling — the reason for this fan. Own OTP 80–110 °C. Do not tie OUT− to IN−. |
| M1 | Fan 5V 0.2A | 1 | Fan, 30×30×10 mm, 5 V, 0.2 A, 2-wire (Raspberry Pi type) | — | ✅ have |  | Runs 1.25 V (off) … ~4.75 V (full). Plug into J3. |
| J5 | DC jack 5.5×2.1 | 1 | DC barrel jack, female, panel mount, 5.5×2.1 mm | Mufa DC mama 5.5x2.1 | ✅ inventory | comp_231 | Center = + (check the 9 V adapter). + goes to SW1; − to ZK-4KX IN− and J1 pin 2. |
| SW1 | DS-431 latching | 1 | Push switch, latching (self-locking), square 14 mm red, snap-in, 2 pins (SPST) | DS-431 | ✅ have |  | Power switch on the front panel, in the + wire from J5 to ZK-4KX IN+ and J1 pin 1. Panel hole ≈ 11.7 × 11.0 mm. Check the DC current rating: ≥ 2 A for the 9 V / 2 A adapter, ≈ 5 A for a 30 V supply at the ZK-4KX's full 30 V / 4 A output. |
| J6 | Banana red | 1 | Banana socket 4 mm, female, red, panel | Mufa Banana 4mm mama rosu | ✅ inventory | comp_226 | ZK-4KX OUT+. |
| J7 | Banana black | 1 | Banana socket 4 mm, female, black, panel | Mufa Banana 4mm mama negru | ✅ inventory | comp_227 | ZK-4KX OUT−. |
| — | M3×16 | 4 | Fan mounting: M3×16 screws + M3 nuts | any | 🛒 buy |  | Through the 2.4 mm left wall of the enclosure base. |
| — | Magnet Ø5×3 | 8 | Neodymium magnet, Ø5 × 3 mm | — | ✅ inventory | comp_193 | Lid: 4 pairs in the corner bosses of the base and cover, glued with CA. Mind the polarity. |

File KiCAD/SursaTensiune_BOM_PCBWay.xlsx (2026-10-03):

 |  |  | ZK-4KX fan controller rev 1.1 — 17 lines BOM (through-hole, single-sided)
Item # | *Designator | *Qty | Manufacturer | *Mfg Part # | Description / Value | *Package/Footprint | Type | Your Instructions / Notes
1 | U1 | 1 | Texas Instruments | LM317T/NOPB | Adjustable linear regulator, 1.5 A, TO-220, THT | TO-220-3_Vertical | thru-hole | Mount on HS1 with the TO-220 insulating kit (pad + shoulder bushing) and an M3 screw before soldering: the tab is OUT and must be isolated from the heatsink (check: open circuit tab-heatsink).
2 | U2 | 1 | Texas Instruments | LM358AP | Dual op-amp, single supply, A-grade (Vos ≤ 3 mV), DIP-8, THT | DIP-8_W7.62mm_Socket | thru-hole | Insert into the DIP-8 socket (XU2), do not solder.
3 | U3 | 1 | Texas Instruments | UA78L05AILP | 5 V / 100 mA linear regulator, TO-92, THT | TO-92_Inline_Wide | thru-hole | Pin 1 (square pad) = OUTPUT; pinout reversed vs 7805. Pads 2.54 mm apart: splay the legs.
4 | R1 | 1 | Yageo | MFR-25FBF52-100K | Resistor, 100 kΩ, 1/4 W, 1 %, axial THT | R_Axial_DIN0207_L6.3mm_D2.5mm_P10.16mm_Horizontal | thru-hole | 1/4 W 1 % metal film, or equivalent.
5 | R2 | 1 | Yageo | MFR-25FBF52-10K | Resistor, 10 kΩ, 1/4 W, 1 %, axial THT | R_Axial_DIN0207_L6.3mm_D2.5mm_P10.16mm_Horizontal | thru-hole | 1/4 W 1 % metal film, or equivalent.
6 | R3 | 1 | Yageo | MFR-25FBF52-100K | Resistor, 100 kΩ, 1/4 W, 1 %, axial THT | R_Axial_DIN0207_L6.3mm_D2.5mm_P10.16mm_Horizontal | thru-hole | 1/4 W 1 % metal film, or equivalent.
7 | R4 | 1 | Yageo | MFR-25FBF52-220R | Resistor, 220 Ω, 1/4 W, 1 %, axial THT | R_Axial_DIN0207_L6.3mm_D2.5mm_P10.16mm_Horizontal | thru-hole | 1/4 W 1 % metal film, or equivalent.
8 | R5 | 1 | Yageo | MFR-25FBF52-100K | Resistor, 100 kΩ, 1/4 W, 1 %, axial THT | R_Axial_DIN0207_L6.3mm_D2.5mm_P10.16mm_Horizontal | thru-hole | 1/4 W 1 % metal film, or equivalent.
9 | RV1 | 1 | Bourns | 3386P-1-103LF | Trimmer, Bourns 3386P, 10 kΩ, single-turn, top adjust, THT | Potentiometer_Bourns_3386P_Vertical | thru-hole
10 | C1,C3,C5 | 3 | Vishay | K104K10X7RF5UH5 | Capacitor, ceramic X7R, 100 nF, 100 V, THT | C_Disc_D5.0mm_W2.5mm_P5.00mm | thru-hole | 5 mm lead pitch.
11 | C2,C4 | 2 | Panasonic | EEA-GA1E100H | Capacitor, aluminium electrolytic, 10 µF, 25 V, radial THT | CP_Radial_D5.0mm_P2.00mm | thru-hole | Polarised: + on the square pad.
12 | D1 | 1 | Any | 1N4007 | Diode, rectifier, 1 A, 1000 V, DO-41, THT | D_DO-41_SOD81_P10.16mm_Horizontal | thru-hole | Band (cathode) on the square pad K.
13 | J1,J3 | 2 | JST | B2B-XH-A | Connector, JST XH 2.54 mm, 2-pin header + housing + crimps | JST_XH_B2B-XH-A_1x02_P2.50mm_Vertical | thru-hole | Header only; latch side as on the silkscreen.
14 | J2 | 1 | JST | B3B-XH-A | Connector, JST XH 2.54 mm, 3-pin header + housing + crimps | JST_XH_B3B-XH-A_1x03_P2.50mm_Vertical | thru-hole | Header only; latch side as on the silkscreen.
15 | XU2 | 1 | Any | DIP-8 socket, 300 mil | IC socket, DIP-8, 300 mil | DIP-8_W7.62mm_Socket | thru-hole | At U2; notch towards pin 1.
16 | HS1 | 1 | Stonecold | RAD-DY-KY/3 | Heatsink, Stonecold RAD-DY-KY/3, TO-220/TO-3P, 40×20 mm profile, 30 mm tall, 2 PCB pins @ 34 mm, M3 thread, 6.9 K/W | Heatsink_Stonecold_RAD-DY-KY-3_40x20mm_P34mm | thru-hole | Heatsink, 2 solder pins; stands 30 mm tall.
17 | U1/HS1 | 1 | Stonecold | TO220-SET | TO-220 insulating mounting set (pad + bushing), Stonecold | Heatsink_Stonecold_RAD-DY-KY-3_40x20mm_P34mm | thru-hole | Insulating kit for U1 on HS1, plus an M3 screw if not in the set.
Need a quick and accurante quote? Need an efficient production? Please read SMT Ordering Necessary Files & Info in 1 minute. Thank you very much! (https://www.pcbway.com/smt_ordering_guide.html)
Click for Instructions on How to Create a BOM (https://www.pcbway.com/blog/PCB_Assembly/How_to_Build_a_BOM__Bill_Of_Materials_.html)

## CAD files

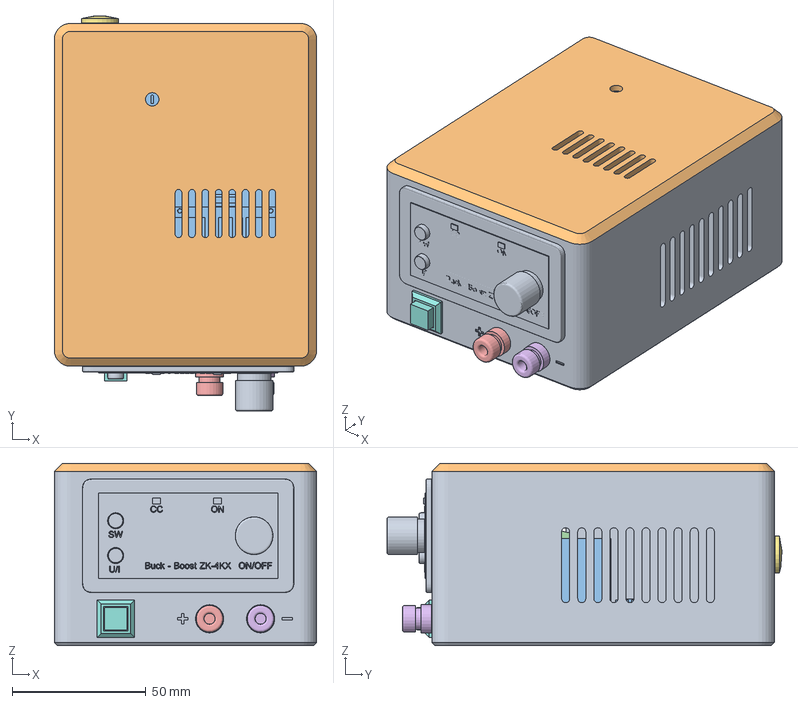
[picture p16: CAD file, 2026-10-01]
mechanical/enclosure/Enclosure_assembly.FCStd
98.0 x 147.5 x 68.0 mm
Base
Cover
Board
Fan
Banana_red
Banana_black
DC_jack
Switch
ZK4KX

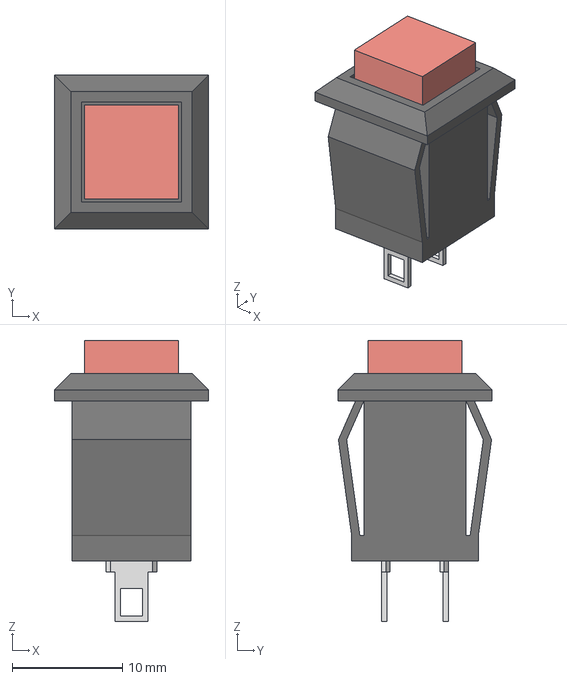
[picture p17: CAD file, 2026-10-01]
mechanical/button/DS-431_square_push_button_red.step
14.0 x 14.0 x 25.5 mm

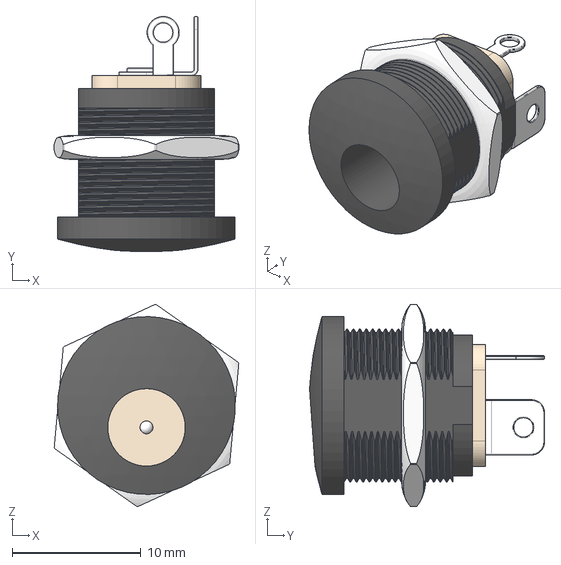
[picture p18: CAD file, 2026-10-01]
mechanical/dc_jack/DC_jack_5.5x2.1_panel_10A.step
14.3 x 18.3 x 15.7 mm

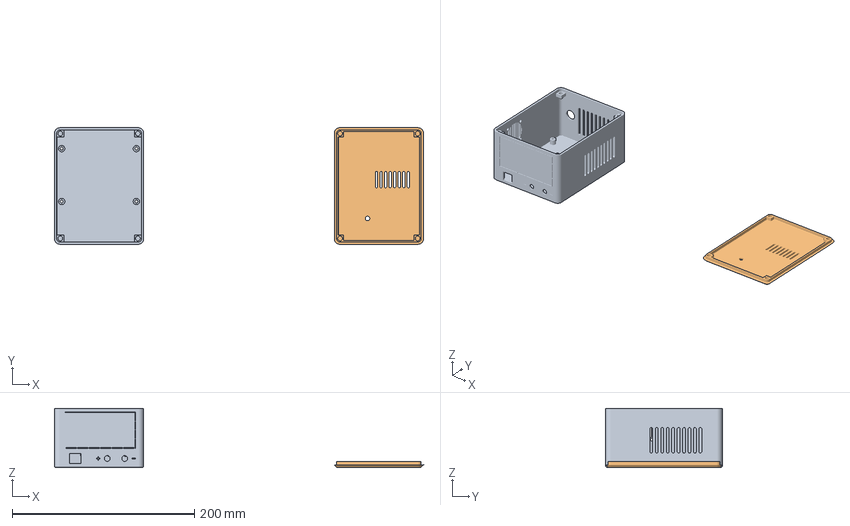
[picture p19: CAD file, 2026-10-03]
mechanical/enclosure/Enclosure_A1_project.3mf
405.2 x 128.0 x 65.0 mm
Enclosure base
Enclosure cover

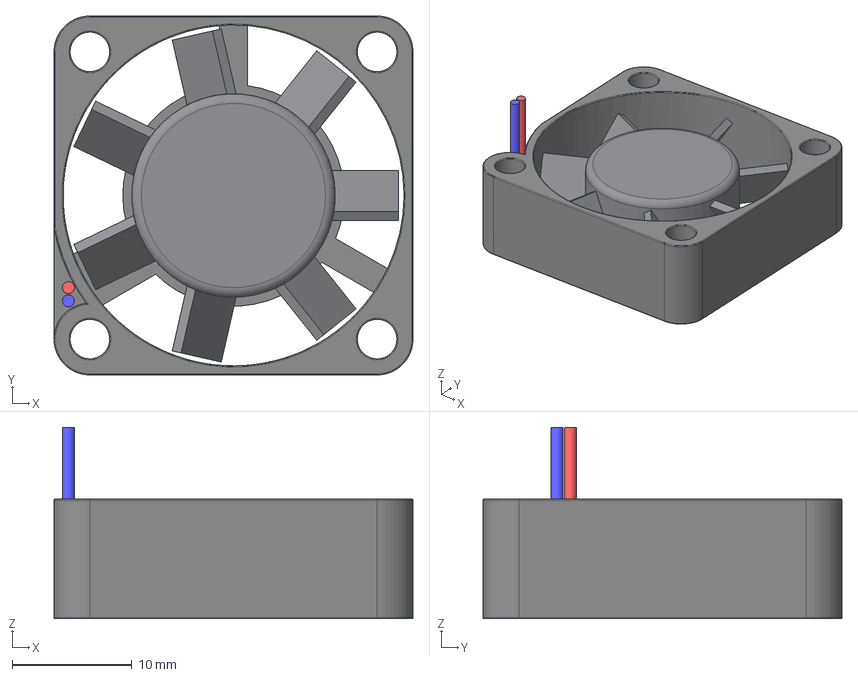
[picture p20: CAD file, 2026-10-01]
mechanical/fan/Fan_30x30x10_5V_2pin.step
30.0 x 30.0 x 16.0 mm
Frame_10mm
Rotor

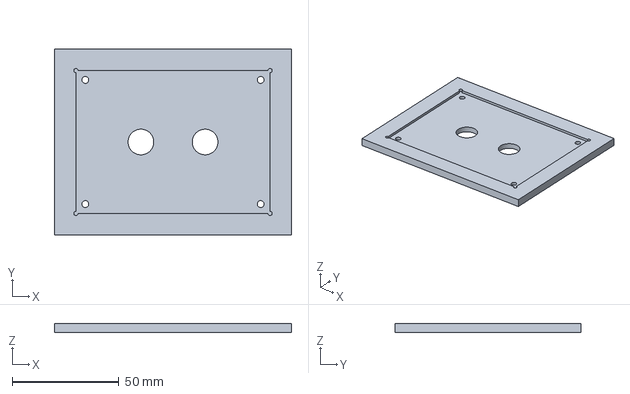
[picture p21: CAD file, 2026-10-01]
mechanical/mask_jig/Mask_jig.step
110.8 x 86.8 x 4.40 mm

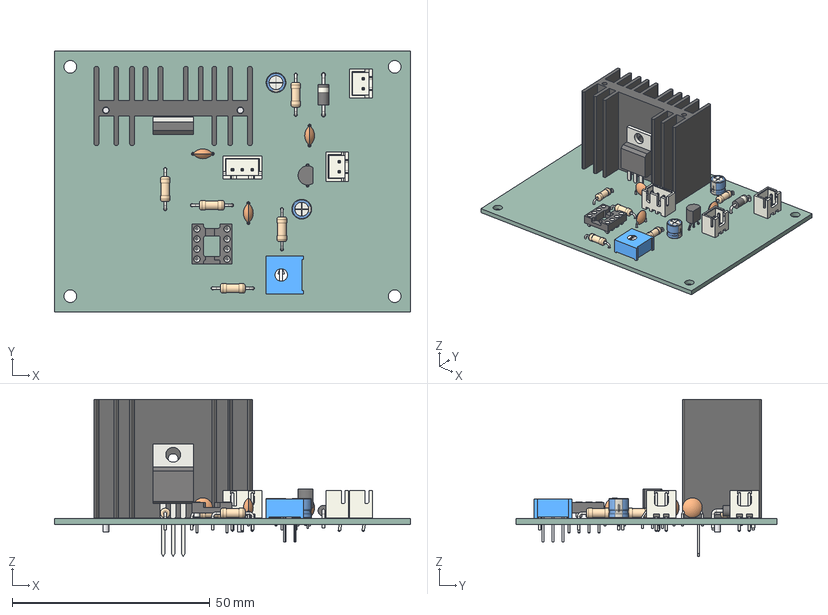
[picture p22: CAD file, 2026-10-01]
mechanical/pcb/SursaTensiune_board.step
90.0 x 66.0 x 39.8 mm
C_Disc_D50mm_W25mm_P500mm x 3
R_Axial_DIN0207_L63mm_D25mm_P1016mm_Horizontal x 5
CP_Radial_D50mm_P200mm x 2
JST_B3B_XH_A
TO-92_Inline_Wide
Heatsink
Pins
TO-220-3_Vertical
D_DO-41_SOD81_P10.16mm_Horizontal
3386P-1-102LF
JST_B2B_XH_A x 2
DIP_8_W762mm_Socket
SursaTensiune_PCB

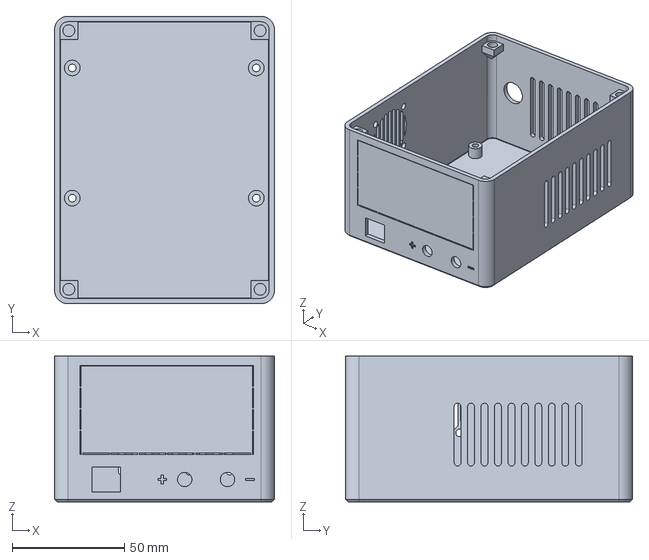
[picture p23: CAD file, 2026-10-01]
mechanical/enclosure/Enclosure_base.step
98.0 x 128.0 x 65.0 mm

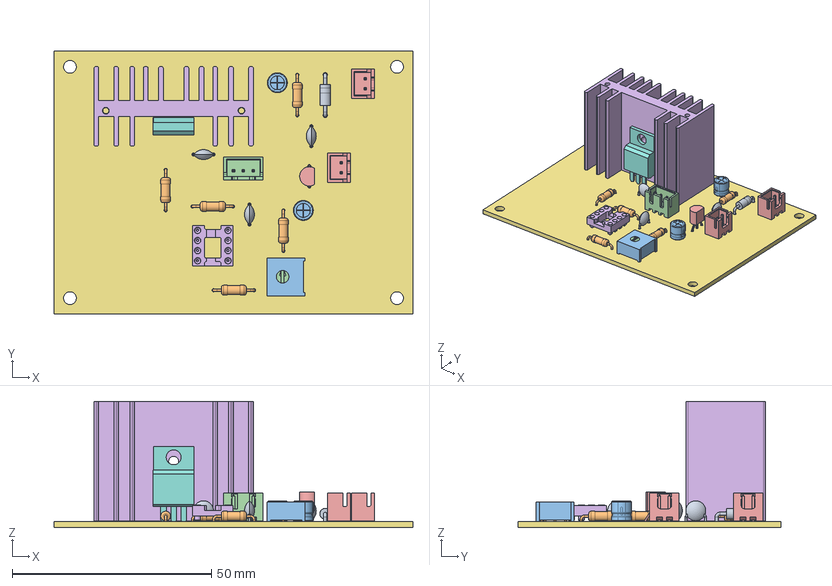
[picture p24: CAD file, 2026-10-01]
mechanical/pcb/SursaTensiune_board_3dprint.step
90.0 x 66.0 x 31.6 mm

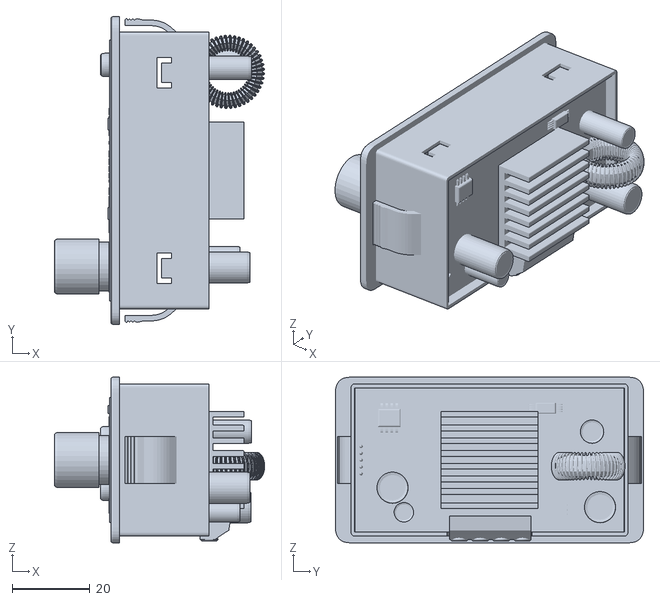
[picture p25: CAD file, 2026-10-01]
mechanical/stl/ZK-4KX Buck Boost Converter.STL
53.9 x 79.0 x 42.5

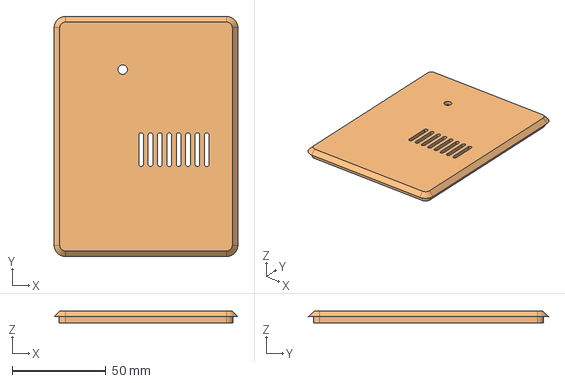
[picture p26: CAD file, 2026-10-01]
mechanical/enclosure/Enclosure_cover.step
98.0 x 128.0 x 6.50 mm

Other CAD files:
mechanical/stl/Fan10.FCStd
mechanical/enclosure/Enclosure_base.3mf
mechanical/enclosure/Enclosure_base.stl
mechanical/enclosure/Enclosure_cover.3mf
mechanical/enclosure/Enclosure_cover.stl
mechanical/mask_jig/Mask_jig.stl
mechanical/pcb/SursaTensiune_board.stl

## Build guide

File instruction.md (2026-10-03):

# Assembly instructions — ZK-4KX bench supply with temperature-controlled fan

Everything needed to build, wire, test and calibrate the unit. Part data: [bom.md](bom.md).
Design details: [README.md](README.md), [KiCAD/PCB_info.md](KiCAD/PCB_info.md), [simulation/](simulation/README.md).

---

## 1. What you are building

```
 9 V adapter ─► DC jack J5 ─► SW1 ──┬─► ZK-4KX  IN+/IN−   ZK-4KX OUT+/OUT− ─► banana J6 (red) / J7 (black)
 (5.5×2.1, centre +)   (on/off, + wire) │
                                    └─► fan board J1 ─► 78L05 (+5 V) ─► LM358 + LM35 ─► LM317 ─► J3 ─► fan M1
                                                  LM35 (on the ZK-4KX heatsink) ─► J2
```

- The fan is **off** below a start temperature **T_start** (set with trimmer RV1, ≈ 15–52 °C).
- Above it, fan speed rises **proportionally**: starts at T_start (≈ 2.8 V), full speed at ≈ T_start + 18 °C (≈ 4.75 V).
- Fail-safes: LM35 disconnected → fan full speed; trimmer wiper open → fan runs from ≈ 17 °C.
- The fan voltage can never exceed ≈ 4.75–5.0 V, whatever the input voltage.

**Input voltage:** 9–28 V (limit set by the 78L05, max ≈ 30 V). The ZK-4KX itself accepts 5–30 V.
With the 9 V / 2 A adapter the ZK-4KX can deliver about 15 W (it draws ≈ 3× the output current when boosting).

---

## 2. Parts and tools

All parts are in [bom.md](bom.md) with inventory IDs. **Still to buy:** 4× M3×10 screws + nuts for the board, 4× M3×16 screws + nuts for the fan.
Check before starting: the JST XH kit shows **qty −5** in the inventory — make sure you have 2× 2-pin and 1× 3-pin headers + housings + crimps.

| Board parts | Off-board parts |
|---|---|
| U1 LM317T/NOPB, U2 LM358AP (+ DIP-8 socket), U3 UA78L05, R1 100k, R2 10k, R3 100k, R4 220 Ω, R5 100k, RV1 3386P 10k trimmer, C1/C3/C5 100 nF, C2/C4 10 µF 25 V, D1 1N4007, J1 XH-2, J2 XH-3, J3 XH-2, HS1 RAD-DY-KY/3 + Stonecold TO220-SET insulating kit | PS1 ZK-4KX, M1 fan 30×30 5 V 0.2 A, U4 LM35DZ, J5 DC jack 5.5×2.1 panel, SW1 DS-431 latching push switch, J6/J7 4 mm banana sockets red/black, Kapton tape, thermal paste, 8× Ø5×3 mm magnets (lid) |

Tools: soldering iron, multimeter, JST XH crimp tool, screwdriver for the trimmer, M3 screwdriver/nut driver, heat-shrink.
Wire: **0.75–1 mm² (AWG 18)** for input and ZK-4KX output (up to 4 A); thin wire (AWG 24–26) for fan and LM35.

---

## 3. Before you build

1. **The PCB is single-sided** (copper on the bottom only, no vias, no wire jumpers), 1.0 mm tracks, GND pour — made
   for toner transfer. Print [KiCAD/toner_B.Cu_1to1.pdf](KiCAD/toner_B.Cu_1to1.pdf) at **100 %** (no fit-to-page),
   **not mirrored**, and check the 90 × 66 mm outline with a ruler. Drills: 0.8 mm (R, C, U2, U3, RV1),
   1.0 mm (J1, J2, J3), 1.1 mm (U1, D1), 2.2 mm (HS1 pins), 3.2 mm (mounting holes). Details:
   [KiCAD/PCB_info.md](KiCAD/PCB_info.md).

   **Printing the films (Canon LBP6020).** Print from the PDF viewer at **Actual size / 100 %**, **A4 portrait**,
   one page at a time: page 1 (B.Cu + mirrored F.SilkS) on thermal transfer paper, page 3 (B.Mask, two copies) on the
   transparency, page 2 on plain paper (assembly reference). Everything is in the top 77 mm of the page — the rest of
   the sheet can be cut off and used for the next print. Driver settings (*Printing Preferences*):

   | Driver setting | Page 1 → thermal transfer paper | Page 3 → Xerox Premium Transparency (003R98198) |
   |---|---|---|
   | Page Setup → Output Size | A4 | A4 (*Transparency* is only offered for A4 / Letter) |
   | Paper Source → Paper Type | **Plain Paper**; switch to **Heavy Paper** (then **Heavy Paper H**) only if the toner rubs off with a fingernail | **Transparency** — never Plain: the fuser runs too hot/fast for film and can melt it onto the roller |
   | Quality → Advanced Settings → Toner Save | **Off** | **Off** |
   | Quality → Advanced Settings → Toner Density | **maximum** | **maximum** |
   | Quality → Advanced Settings → Halftones | **None [Solid]** (no dither in the GND pour) | **None [Solid]** |
   | Finishing → Advanced Settings → Special Print Mode A/B, Special Print Adjustment A/B | Off (they all lower density) | Off |
   | Finishing → Advanced Settings → Output Adjustment Mode | On (higher resolution for the 0.5 mm clearances) | On |

   - **Which side prints:** on the LBP6020 load the sheet with the side to print **facing up**. Check once with a plain
     sheet marked with an X before wasting a transfer sheet or a film.
   - **Feed one sheet at a time**, holding it by the edges (fingerprints stop toner from sticking). Transfer paper:
     print on the **glossy/coated side**. Transparency: laser-grade film, fan it first. The removable stripe must not
     lie under a board (boards: 11–77 mm from the top edge, 11–201 mm across) — if it runs along a short edge, feed
     that edge last so it ends up at the bottom of the page.
   - Take each sheet out as soon as it comes out, let it cool flat, don't touch the toner. Check for pinholes against
     a lamp: a pinhole in the GND pour becomes a pit in the copper.
   - **Solder mask film:** laser toner does not fully block UV, so page 3 has **two copies**. Cut them apart and stack
     them exactly on top of each other (align on the pads over a lamp, a drop of superglue or tape at the corners). Expose with the
     toner side towards the board — less parallax. Black = pad openings; the rest of the UV mask hardens.
2. **Measure the real parts** and correct the footprints if needed (then re-run `KiCAD/gen/gen_heatsink.py`):
   - Heatsink RAD-DY-KY/3: pin diameter (hole is 2.2 mm), pin spacing (34 mm), fin gap on the flat side (≈ 19.6 mm), **height of the M3 hole**.
   - 100 nF capacitors: lead pitch (footprint 5.0 mm).
3. **Adapter polarity:** the design assumes a **centre-positive** 9 V adapter — check its label.

---

## 4. Board assembly (low parts first)

Pin 1 of every part is the **square pad**.

| Step | Part | Notes |
|---|---|---|
| 1 | R1–R5 | Not polarised. R1, R3, R5 = 100 kΩ, R2 = 10 kΩ, R4 = 220 Ω. |
| 2 | D1 1N4007 | **Band (cathode) on the square pad "K"** — cathode goes to V_FAN. |
| 3 | DIP-8 socket | Notch towards pin 1. Do **not** insert U2 yet. |
| 4 | C1, C3, C5 100 nF | Not polarised. C1 at U1, C3 at U3, C5 beside U2 (on its +5 V track). |
| 5 | RV1 trimmer 3386P | Only fits one way. |
| 6 | U3 UA78L05 (TO-92) | Pads are 2.54 mm apart (wider than the TO-92 legs, for home etching) — splay the legs slightly. Pin 1 (square pad) = **OUTPUT**, 2 = GND, 3 = INPUT. Its pinout is reversed vs a 7805 — follow the pad numbers, not the 7805 habit. |
| 7 | C2, C4 10 µF | **+ on the square pad.** Stripe (−) away from it. |
| 8 | J1, J2, J3 JST XH | Latch side as printed on the silkscreen. |
| 9 | HS1 heatsink | Solder its two pins. It stands 30 mm tall. |
| 10 | U1 LM317T | See below. |

### Mounting U1 on the heatsink
The LM317 tab is connected to its **OUT** pin (= V_FAN), so it **must be insulated** from the heatsink.

1. Put U1's legs through the board **without soldering**.
2. Stack: heatsink ← insulating pad (from the TO220-SET) ← U1 tab ← shoulder bushing ← M3 screw (+ washer/nut if the set has none).
   The screw goes into the heatsink's **M3 thread**.
3. Adjust U1's height so the tab hole lines up with the heatsink hole — if the hole is at mid-height (15 mm),
   the TO-220 body stands **≈ 2 mm above the PCB**.
4. Tighten moderately (soft pad — do not crush it).
5. **Check isolation:** multimeter on Ω between the heatsink and U1's tab/middle pin → must read **open (OL)**.
6. Only now solder U1's three legs. Pin 1 (square pad) = ADJ, 2 = OUT, 3 = IN.

At 9 V input U1 dissipates ≈ 0.9 W; at 30 V ≈ 5.3 W (Tj ≈ ambient + 58 °C with this heatsink).

---

## 5. Enclosure and wiring

Printed case: [mechanical/enclosure/](mechanical/enclosure/README.md) — an open base (floor + all 4 walls) and a top cover.
Front panel: ZK-4KX on top; below it, left to right: power switch SW1, red **+**, black **−**. DC jack on the rear.
Board on the 4 × 6 mm standoffs printed in the base (M3×10 + nuts in the hex pockets under the floor), fan on the base's left wall
(4 × M3×16 + nuts), cover held by 4 pairs of Ø5×3 mm magnets glued into the corners (mind the polarity — see the
[enclosure notes](mechanical/enclosure/README.md#assembly)). A Ø5 hole in the cover gives access to the trimmer RV1.
**Trim all board leads to ≤ 3 mm** below the PCB (6 mm standoffs).

### ZK-4KX (PS1)
- Panel cutout **71 × 39 mm**; body 79 × 43 × 26 mm (model: `mechanical/stl/`).
- Terminal block on the back: **IN+, IN−, OUT+, OUT−**.
- **Never connect OUT− to IN−** (the module measures current between them). Never short IN to OUT.

### DC jack J5 (panel, 3 tabs)
The jack has three tabs: **centre pin**, **sleeve**, and a **switch** contact (touches the sleeve only when no plug is inserted).
Identify them with the multimeter (continuity) before soldering: plug in the adapter's connector and see which tab
connects to the plug's barrel — that is the sleeve; the switch tab loses contact when the plug goes in. Leave the switch tab unconnected.

### Power switch SW1 (DS-431, front panel)
Latching push switch with 2 pins: pressed in = **on**, pressed again = **off**. It sits in the **+ wire**, before the
split to the ZK-4KX and the fan board, so it switches both (off = no fan either). It snaps into an ≈ 11.7 × 11.0 mm
hole from the front. Before soldering, check with the multimeter which state is "on" (continuity when latched in).
**Current rating:** read the rating on the switch body — it must be ≥ 2 A DC for the 9 V / 2 A adapter. With a 30 V
supply and the ZK-4KX at its full 30 V / 4 A, the input current is ≈ 5 A; a small switch is not rated for that.

### Wiring table
| From | To | Wire |
|---|---|---|
| J5 DC jack centre (+) | **SW1** pin 1 | 0.75–1 mm² |
| **SW1** pin 2 | ZK-4KX **IN+** and board **J1 pin 1** | 0.75–1 mm² to the ZK-4KX, thin to J1 |
| J5 DC jack sleeve (−) | ZK-4KX **IN−** and board **J1 pin 2** | same (not switched) |
| ZK-4KX **OUT+** | J6 red banana | 0.75–1 mm² |
| ZK-4KX **OUT−** | J7 black banana | 0.75–1 mm² |
| Fan red (+) / black (−) | board **J3 pin 1 / pin 2** | fan leads |
| LM35 +Vs / Vout / GND | board **J2 pin 1 / 2 / 3** | 3 thin wires |

### LM35 (U4) on the ZK-4KX heatsink
The ZK-4KX has a finned aluminium heatsink in the middle of its back PCB, above the terminal block
(the switching MOSFETs are under it) — that is the hot spot to measure.

1. **Measure the heatsink potential first:** multimeter between the heatsink and IN− with the module powered.
   If it is not 0 V (it may be tied to a MOSFET / switching node), the LM35 legs must not touch it.
2. Flat face of the LM35 against the heatsink base at the fin root, with a little thermal paste; fix with Kapton
   (or thermally conductive epoxy).
3. Insulate the three legs (Kapton or heat-shrink). Check the LM35 pinout (+Vs, Vout, GND) against the TI datasheet
   drawing before soldering the wires — a reversed LM35 heats up and reads nonsense.
4. Route the wires away from the toroid inductor. If they are **longer than ≈ 20 cm**, add a 75–100 Ω resistor in series
   with 1 µF from Vout to GND at the sensor (datasheet damper).

### Fan (M1) and board
- Place the fan so it blows **onto the ZK-4KX's rear heatsink**; give the enclosure inlet and outlet vents.
  The fan is **10 mm** thick (STEP model: `mechanical/fan/Fan_30x30x10_5V_2pin.step`).
- Mount the board on the printed standoffs; keep the **trimmer RV1 reachable** with a screwdriver and U2 pin 7 reachable
  with a probe (for calibration).
- HS1 is not connected to any net (U1's tab is insulated from it) — still keep it clear of other metal.

---

## 6. First power-up

Use the 9 V adapter (or a bench supply with current limit ≈ 200 mA for the board alone).

1. **U2 out of its socket and the fan unplugged.** Do **not** power the board with the fan connected while U2 is
   missing: the LM317's ADJ pin would float and V_FAN would rise towards V_in.
2. Power on (SW1 latched in). Measure to GND:
   - J1 pin 1 (VIN): ≈ 9 V
   - C4 + (or U2 socket pin 8): **4.75–5.25 V**. If not, check U3's orientation.
3. Power off. Insert **U2 LM358AP** (notch to pin 1). Plug in the fan (J3) and the LM35 (J2).
4. Power on. At room temperature with T_start set above it, V_FAN (C2 +) ≈ **1.25 V** and the fan does not spin.

---

## 7. Calibration — setting the start temperature

Measure **U2 pin 7 to GND** (V_REF) and turn RV1 (clockwise = hotter):

> **V_REF [mV] = 11 × T_start − 155**

| Fan starts at | V_REF (U2 pin 7) |
|---|---|
| 35 °C | 230 mV |
| 40 °C | 285 mV |
| 45 °C | 340 mV |
| 50 °C | 395 mV |
| 52 °C (≈ max) | 417 mV |

Recommended start: **40–45 °C** on the ZK-4KX heatsink. The fan reaches full speed ≈ 18 °C higher,
well before the ZK-4KX's own over-temperature protection (settable 80–110 °C).

**Check:** warm the LM35 (fingers, hair dryer). LM35 output (J2 pin 2) = 10 mV/°C. The fan should start near T_start
and V_FAN should rise ≈ 0.11 V/°C up to ≈ 4.75 V.

Narrower ramp (≈ 9.5 °C instead of 18 °C): replace R2 with 5.1 kΩ (then V_REF = (20.6·T_start/100 − 1.55) / 19.6 V).

---

## 8. Troubleshooting

| Symptom | Check |
|---|---|
| Nothing works | SW1 off (latched out), or its rating/contacts — measure VIN on both SW1 pins |
| No +5 V | U3 reversed (pin 1 = OUTPUT), C3/C4 shorted, VIN missing on J1 |
| Fan always full speed | LM35 disconnected or wrongly wired (fail-safe → full), J2 pinout |
| Fan never starts | V_REF too high (turn RV1 anticlockwise); LM35 reading low; fan needs > 2.8 V to start — lower T_start a little |
| Fan starts at ≈ 17 °C regardless of RV1 | RV1 wiper not contacting (R5 fail-safe active) |
| V_FAN > 5 V | U2 missing or ADJ (U1 pin 1) not connected to U2 pin 1 |
| Heatsink shorts / fan voltage wrong | U1 tab not insulated — check the TO220-SET pad and bushing |
| U1 very hot | Input voltage high: 5.3 W at 30 V is normal for this design; make sure HS1 gets airflow |

---

## 9. Reference values

| Point | Value |
|---|---|
| +5 V rail (U3 out) | 4.75–5.25 V |
| V_REF (U2 pin 7) | 0 … ≈ 0.42 V (sets T_start) |
| LM35 out (J2 pin 2) | 10 mV/°C (e.g. 0.40 V at 40 °C) |
| V_ADJ (U2 pin 1) | 11·V_LM35 − 10·V_REF, 0 … ≈ 3.5 V |
| V_FAN (J3 pin 1) | V_ADJ + 1.25 V → 1.25 V (off) … ≈ 4.75 V (full) |
| U1 dissipation | 0.9 W @ 9 V in, 5.3 W @ 30 V in |

Simulated in ngspice and LTspice (11 scenarios, all pass in both): [ngspice](simulation/ngspice/results/RESULTS.md), [LTspice](simulation/ltspice/results/RESULTS.md).

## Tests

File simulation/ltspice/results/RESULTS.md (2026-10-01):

# Simulation results — LTspice, behavioral models

> Generated by `ltspice/run_sim.py --all`.

| Scenario | Description | Result |
|---|---|---|
| [A_nominal_40C](A_nominal_40C/plot.png) | Temperature sweep, threshold set for 40 °C, 9 V in | ✅ PASS |
| [B_pot_min](B_pot_min/plot.png) | Temperature sweep, pot at minimum | ✅ PASS |
| [C_pot_max](C_pot_max/plot.png) | Temperature sweep, pot at maximum | ✅ PASS |
| [D_vin_sweep_hot](D_vin_sweep_hot/plot.png) | Input sweep 6–30 V at 70 °C (fan full) | ✅ PASS |
| [E_powerup_9V_hot](E_powerup_9V_hot/plot.png) | Power-up 0→9 V at 70 °C | ✅ PASS |
| [F_powerup_30V_hot](F_powerup_30V_hot/plot.png) | Power-up 0→30 V at 70 °C | ✅ PASS |
| [G_powerup_9V_cold](G_powerup_9V_cold/plot.png) | Power-up 0→9 V at 25 °C (fan should stay off) | ✅ PASS |
| [H_wiper_open](H_wiper_open/plot.png) | Fault: pot wiper open, worst-case LM358 bias 250 nA | ✅ PASS |
| [I_sensor_open](I_sensor_open/plot.png) | Fault: LM35 disconnected | ✅ PASS |
| [J_offset_worst_pos](J_offset_worst_pos/plot.png) | LM358 offset corner: U2A +7 mV, U2B −7 mV (uncalibrated) | ✅ PASS |
| [K_offset_worst_neg](K_offset_worst_neg/plot.png) | LM358 offset corner: U2A −7 mV, U2B +7 mV (uncalibrated) | ✅ PASS |

## Details

### A_nominal_40C

- PASS  25 °C: V_fan = 1.25 V (fan off, < 1.6 V)
- PASS  fan start (2.8 V) at 40.1 °C (expected 40.0 ± 1.0 °C)
- PASS  62 °C: V_fan = 4.74 V (full speed, ≥ 4.5 V)
- PASS  max V_fan = 4.740 V (limit 5.25 V)

### B_pot_min

- PASS  pot at minimum: fan start at 14.7 °C (≤ 15 °C)

### C_pot_max

- PASS  pot at maximum: fan start at 52.1 °C (46–53 °C)

### D_vin_sweep_hot

- PASS  V_in 8.5–30 V: V_fan 4.740–4.740 V (4.5–5.25 V)
- PASS  U1 (LM317) dissipation @ 9 V in: 0.90 W (no heatsink needed, < 1.2 W)
- PASS  U1 (LM317) dissipation @ 30 V in: 5.33 W (heatsink HS1 required)

### E_powerup_9V_hot

- PASS  max V_fan = 4.741 V (limit 5.25 V)
- PASS  settled V_fan = 4.740 V

### F_powerup_30V_hot

- PASS  max V_fan = 4.740 V (limit 5.25 V)
- PASS  settled V_fan = 4.740 V

### G_powerup_9V_cold

- PASS  cold power-up: max V_fan = 1.68 V (no start-up kick, < 2.0 V)

### H_wiper_open

- PASS  wiper open, worst-case IB: fan start at 16.6 °C (fail-safe ON, ≤ 20 °C)

### I_sensor_open

- PASS  sensor open: V_fan ≥ 4.74 V at all temperatures (fail-safe full speed)

### J_offset_worst_pos

- PASS  fan start (2.8 V) at 38.8 °C (expected 40.0 ± 1.5 °C)
- PASS  max V_fan = 4.740 V (limit 5.25 V)

### K_offset_worst_neg

- PASS  fan start (2.8 V) at 41.5 °C (expected 40.0 ± 1.5 °C)
- PASS  max V_fan = 4.740 V (limit 5.25 V)

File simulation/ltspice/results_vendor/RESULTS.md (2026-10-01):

# Simulation results — LTspice, vendor models

> Generated by `ltspice/run_sim.py --all --vendor`.

| Scenario | Description | Result |
|---|---|---|
| [A_nominal_40C](A_nominal_40C/plot.png) | Temperature sweep, threshold set for 40 °C, 9 V in | ✅ PASS |
| [B_pot_min](B_pot_min/plot.png) | Temperature sweep, pot at minimum | ❌ FAIL |
| [C_pot_max](C_pot_max/plot.png) | Temperature sweep, pot at maximum | ✅ PASS |
| [D_vin_sweep_hot](D_vin_sweep_hot/plot.png) | Input sweep 6–30 V at 70 °C (fan full) | ✅ PASS |
| [E_powerup_9V_hot](E_powerup_9V_hot/plot.png) | Power-up 0→9 V at 70 °C | ✅ PASS |
| [F_powerup_30V_hot](F_powerup_30V_hot/plot.png) | Power-up 0→30 V at 70 °C | ✅ PASS |
| [G_powerup_9V_cold](G_powerup_9V_cold/plot.png) | Power-up 0→9 V at 25 °C (fan should stay off) | ✅ PASS |
| [H_wiper_open](H_wiper_open/plot.png) | Fault: pot wiper open, worst-case LM358 bias 250 nA | ❌ FAIL |
| [I_sensor_open](I_sensor_open/plot.png) | Fault: LM35 disconnected | ✅ PASS |
| [J_offset_worst_pos](J_offset_worst_pos/plot.png) | LM358 offset corner: U2A +7 mV, U2B −7 mV (uncalibrated) | ✅ PASS |
| [K_offset_worst_neg](K_offset_worst_neg/plot.png) | LM358 offset corner: U2A −7 mV, U2B +7 mV (uncalibrated) | ✅ PASS |

## Details

### A_nominal_40C

- PASS  25 °C: V_fan = 1.47 V (fan off, < 1.6 V)
- PASS  fan start (2.8 V) at 40.0 °C (expected 40.0 ± 1.0 °C)
- PASS  62 °C: V_fan = 4.90 V (full speed, ≥ 4.5 V)
- PASS  max V_fan = 4.901 V (limit 5.25 V)

### B_pot_min

- FAIL  pot at minimum: fan start at 22.7 °C (≤ 15 °C)

### C_pot_max

- PASS  pot at maximum: fan start at 52.0 °C (46–53 °C)

### D_vin_sweep_hot

- PASS  V_in 8.5–30 V: V_fan 4.901–4.901 V (4.5–5.25 V)
- PASS  U1 (LM317) dissipation @ 9 V in: 0.89 W (no heatsink needed, < 1.2 W)
- PASS  U1 (LM317) dissipation @ 30 V in: 5.48 W (heatsink HS1 required)

### E_powerup_9V_hot

- PASS  max V_fan = 4.914 V (limit 5.25 V)
- PASS  settled V_fan = 4.901 V

### F_powerup_30V_hot

- PASS  max V_fan = 4.915 V (limit 5.25 V)
- PASS  settled V_fan = 4.901 V

### G_powerup_9V_cold

- PASS  cold power-up: max V_fan = 1.50 V (no start-up kick, < 2.0 V)

### H_wiper_open

- FAIL  wiper open, worst-case IB: fan start at 23.0 °C (fail-safe ON, ≤ 20 °C)

### I_sensor_open

- PASS  sensor open: V_fan ≥ 4.90 V at all temperatures (fail-safe full speed)

### J_offset_worst_pos

- PASS  fan start (2.8 V) at 38.7 °C (expected 40.0 ± 1.5 °C)
- PASS  max V_fan = 4.900 V (limit 5.25 V)

### K_offset_worst_neg

- PASS  fan start (2.8 V) at 41.3 °C (expected 40.0 ± 1.5 °C)
- PASS  max V_fan = 4.901 V (limit 5.25 V)

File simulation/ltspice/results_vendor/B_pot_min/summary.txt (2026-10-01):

B_pot_min: Temperature sweep, pot at minimum
FAIL  pot at minimum: fan start at 22.7 °C (≤ 15 °C)

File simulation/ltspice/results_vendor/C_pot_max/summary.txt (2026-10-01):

C_pot_max: Temperature sweep, pot at maximum
PASS  pot at maximum: fan start at 52.0 °C (46–53 °C)

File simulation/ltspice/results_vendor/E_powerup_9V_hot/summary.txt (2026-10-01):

E_powerup_9V_hot: Power-up 0→9 V at 70 °C
PASS  max V_fan = 4.914 V (limit 5.25 V)
PASS  settled V_fan = 4.901 V

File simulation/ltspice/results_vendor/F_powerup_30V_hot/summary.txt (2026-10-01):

F_powerup_30V_hot: Power-up 0→30 V at 70 °C
PASS  max V_fan = 4.915 V (limit 5.25 V)
PASS  settled V_fan = 4.901 V

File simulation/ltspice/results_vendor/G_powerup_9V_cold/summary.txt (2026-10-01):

G_powerup_9V_cold: Power-up 0→9 V at 25 °C (fan should stay off)
PASS  cold power-up: max V_fan = 1.50 V (no start-up kick, < 2.0 V)

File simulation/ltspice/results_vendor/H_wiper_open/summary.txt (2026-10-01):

H_wiper_open: Fault: pot wiper open, worst-case LM358 bias 250 nA
FAIL  wiper open, worst-case IB: fan start at 23.0 °C (fail-safe ON, ≤ 20 °C)

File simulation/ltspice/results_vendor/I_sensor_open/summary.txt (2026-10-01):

I_sensor_open: Fault: LM35 disconnected
PASS  sensor open: V_fan ≥ 4.90 V at all temperatures (fail-safe full speed)

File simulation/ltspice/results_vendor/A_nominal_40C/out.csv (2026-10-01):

sweep | vin | t | v5 | vref | vadj | vfan | i317 | ifan
0.0 | 9.0 | 0.0 | 4.9999008695395135 | 0.2852249860471405 | 0.21338229672935047 | 1.4701844708264282 | 0.06549003657042007 | 0.058807378830944716
0.0020000000000002655 | 9.0 | 0.0020000000000002655 | 4.999900869539716 | 0.28522498619367237 | 0.21338229961608227 | 1.4701844730371436 | 0.06549003856137281 | 0.058807378921468575
0.006000000000000796 | 9.0 | 0.006000000000000796 | 4.999900869539845 | 0.28522498596728957 | 0.21338230067451486 | 1.4701844747810362 | 0.06549003946572496 | 0.058807378991232326
0.014000000000000123 | 9.0 | 0.014000000000000123 | 4.999900869539841 | 0.28522498604447477 | 0.21338230119169452 | 1.4701844756035078 | 0.06549003871132131 | 0.058807379024140224
0.030000000000000512 | 9.0 | 0.030000000000000512 | 4.999900869539821 | 0.28522498605301766 | 0.2133823017692018 | 1.4701844760130305 | 0.06549003738213388 | 0.058807379040522544
0.0499999999999997 | 9.0 | 0.0499999999999997 | 4.999900869539813 | 0.28522498605217467 | 0.2133823025590265 | 1.4701844766545558 | 0.06549003707537282 | 0.058807379066200774
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

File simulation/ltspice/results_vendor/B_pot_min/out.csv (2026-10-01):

sweep | vin | t | v5 | vref | vadj | vfan | i317 | ifan
0.0 | 9.0 | 0.0 | 4.999853510152841 | 0.041566672368943604 | 0.18864285540181747 | 1.4454459303037905 | 0.0643880471012297 | 0.05781783721215398
0.0020000000000002655 | 9.0 | 0.0020000000000002655 | 4.999853510152879 | 0.0415667065249176 | 0.1886428599011024 | 1.4454459338238648 | 0.06438805024474958 | 0.05781783735516104
0.006000000000000796 | 9.0 | 0.006000000000000796 | 4.999853510152894 | 0.04156673331377837 | 0.18864286411138673 | 1.4454459384914167 | 0.06438805323003138 | 0.05781783753965335
0.014000000000000123 | 9.0 | 0.014000000000000123 | 4.9998535101528665 | 0.04156678563829022 | 0.1886428718561781 | 1.445445946637281 | 0.06438805624154531 | 0.0578178378654908
0.030000000000000512 | 9.0 | 0.030000000000000512 | 4.999853510152821 | 0.0415668906844288 | 0.1886428872234738 | 1.4454459621513085 | 0.06438805849813045 | 0.05781783848605262
0.0499999999999997 | 9.0 | 0.0499999999999997 | 4.999853510152768 | 0.04156702203831483 | 0.18864290637679074 | 1.4454459813324134 | 0.06438805942378323 | 0.05781783925329125
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

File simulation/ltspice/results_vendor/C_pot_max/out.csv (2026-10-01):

sweep | vin | t | v5 | vref | vadj | vfan | i317 | ifan
0.0 | 9.0 | 0.0 | 4.999900748839541 | 0.41701782430437806 | 0.24409843362503778 | 1.5008994950574033 | 0.06685825131558258 | 0.06003597980229942
0.0020000000000002655 | 9.0 | 0.0020000000000002655 | 4.999900748839745 | 0.41701782444573726 | 0.24409843900443798 | 1.5008994992764413 | 0.06685825494689633 | 0.06003597996723404
0.006000000000000796 | 9.0 | 0.006000000000000796 | 4.999900748839859 | 0.41701782422332706 | 0.24409844196267835 | 1.500899503146533 | 0.06685825736078573 | 0.06003598013301299
0.014000000000000123 | 9.0 | 0.014000000000000123 | 4.999900748839837 | 0.41701782429869017 | 0.2440984434311944 | 1.5008995054171774 | 0.06685825601752872 | 0.06003598021410511
0.030000000000000512 | 9.0 | 0.030000000000000512 | 4.99990074883978 | 0.4170178243052817 | 0.24409844304118075 | 1.5008995047969607 | 0.06685825221896702 | 0.06003598019189835
0.0499999999999997 | 9.0 | 0.0499999999999997 | 4.9999007488397265 | 0.41701782430509593 | 0.24409844262675898 | 1.5008995040751656 | 0.06685825102143023 | 0.06003598016303943
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

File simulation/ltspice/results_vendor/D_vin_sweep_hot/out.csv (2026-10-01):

sweep | vin | t | v5 | vref | vadj | vfan | i317 | ifan
6.0 | 6.0 | 70.0 | 4.299964596490137 | 0.24532456186731666 | 2.9394493228787835 | 4.0786738158355895 | 0.1816863803425011 | 0.1631469526262964
6.002000000000001 | 6.002000000000001 | 70.0 | 4.301293499564688 | 0.24539651011290545 | 2.9407706264939746 | 4.080086503270977 | 0.1829269690073494 | 0.1632034792781865
6.006000000000001 | 6.006000000000001 | 70.0 | 4.304895951476634 | 0.24559916935089504 | 2.944262431986135 | 4.08307179601771 | 0.18508727836445651 | 0.16332287225845704
6.01268299613837 | 6.01268299613837 | 70.0 | 4.311575592873036 | 0.24598000120880678 | 2.9507478607070645 | 4.088488248173654 | 0.18779709004453649 | 0.16353953872934698
6.019849048481697 | 6.019849048481697 | 70.0 | 4.318792468302461 | 0.24639181363738968 | 2.957796012688893 | 4.094737051650656 | 0.1897678768631601 | 0.16378949254594627
6.031478522493271 | 6.031478522493271 | 70.0 | 4.330435568457399 | 0.24705570513301056 | 2.969225549618448 | 4.105445477038941 | 0.19175232867032707 | 0.1642178373580567
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

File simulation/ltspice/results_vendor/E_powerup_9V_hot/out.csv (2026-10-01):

sweep | vin | t | v5 | vref | vadj | vfan | i317 | ifan
0.0 | 0.0 | 70.0 | -8.285654576201212e-06 | 0.017931753053273103 | 0.017931823719064616 | -6.576787382953665e-08 | -2.929661112172862e-09 | -2.630714953181466e-09
2.9296876036255526e-10 | 0.0 | 70.0 | -8.285654576201213e-06 | 0.017931753053273148 | 0.017931823719064616 | -6.576787383136834e-08 | -2.929661114081008e-09 | -2.630714953254539e-09
5.859375207251105e-10 | 0.0 | 70.0 | -8.285654576201213e-06 | 0.017931753053273193 | 0.01793182371906462 | -6.576787383107837e-08 | -2.929661113766211e-09 | -2.630714953242486e-09
1.171875041450221e-09 | 0.0 | 70.0 | -8.28565457620121e-06 | 0.017931753053273207 | 0.01793182371906462 | -6.576787383281486e-08 | -2.9296611156222794e-09 | -2.6307149533135675e-09
2.343750082900442e-09 | 0.0 | 70.0 | -8.285654576201212e-06 | 0.017931753053273273 | 0.01793182371906461 | -6.576787383495811e-08 | -2.9296611177600805e-09 | -2.6307149533954518e-09
4.687500165800884e-09 | 0.0 | 70.0 | -8.285654576201205e-06 | 0.017931753053273203 | 0.017931823719064637 | -6.57678738312962e-08 | -2.9296611139907616e-09 | -2.6307149532511344e-09
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

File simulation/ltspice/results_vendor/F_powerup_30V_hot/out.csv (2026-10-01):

sweep | vin | t | v5 | vref | vadj | vfan | i317 | ifan
0.0 | 0.0 | 70.0 | -8.285654576201212e-06 | 0.017931753053273103 | 0.017931823719064616 | -6.576787382953665e-08 | -2.929661112172862e-09 | -2.630714953181466e-09
2.9296876036255526e-10 | 0.0 | 70.0 | -8.285654576201213e-06 | 0.017931753053273148 | 0.017931823719064616 | -6.576787383136834e-08 | -2.929661114081008e-09 | -2.630714953254539e-09
5.859375207251105e-10 | 0.0 | 70.0 | -8.285654576201213e-06 | 0.017931753053273193 | 0.01793182371906462 | -6.576787383107837e-08 | -2.929661113766211e-09 | -2.630714953242486e-09
1.171875041450221e-09 | 0.0 | 70.0 | -8.28565457620121e-06 | 0.017931753053273207 | 0.01793182371906462 | -6.576787383281486e-08 | -2.9296611156222794e-09 | -2.6307149533135675e-09
2.343750082900442e-09 | 0.0 | 70.0 | -8.285654576201212e-06 | 0.017931753053273273 | 0.01793182371906461 | -6.576787383495811e-08 | -2.9296611177600805e-09 | -2.6307149533954518e-09
4.687500165800884e-09 | 0.0 | 70.0 | -8.285654576201205e-06 | 0.017931753053273203 | 0.017931823719064637 | -6.57678738312962e-08 | -2.9296611139907616e-09 | -2.6307149532511344e-09
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

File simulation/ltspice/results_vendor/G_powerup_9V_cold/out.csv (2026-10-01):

sweep | vin | t | v5 | vref | vadj | vfan | i317 | ifan
0.0 | 0.0 | 25.0 | -8.285654576201234e-06 | 0.017931753053273103 | 0.017931823719064616 | -6.576787382953665e-08 | -2.929661112172862e-09 | -2.630714953181466e-09
2.9296876036255526e-10 | 0.0 | 25.0 | -8.285654576201235e-06 | 0.017931753053273148 | 0.017931823719064616 | -6.576787383136834e-08 | -2.929661114081008e-09 | -2.630714953254539e-09
5.859375207251105e-10 | 0.0 | 25.0 | -8.285654576201234e-06 | 0.017931753053273193 | 0.01793182371906462 | -6.576787383107837e-08 | -2.929661113766211e-09 | -2.630714953242486e-09
1.171875041450221e-09 | 0.0 | 25.0 | -8.28565457620123e-06 | 0.017931753053273207 | 0.01793182371906462 | -6.576787383281486e-08 | -2.9296611156222794e-09 | -2.6307149533135675e-09
2.343750082900442e-09 | 0.0 | 25.0 | -8.285654576201232e-06 | 0.017931753053273273 | 0.01793182371906461 | -6.576787383495811e-08 | -2.9296611177600805e-09 | -2.6307149533954518e-09
4.687500165800884e-09 | 0.0 | 25.0 | -8.285654576201225e-06 | 0.017931753053273203 | 0.017931823719064637 | -6.57678738312962e-08 | -2.9296611139907616e-09 | -2.6307149532511344e-09
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

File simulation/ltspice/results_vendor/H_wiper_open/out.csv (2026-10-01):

sweep | vin | t | v5 | vref | vadj | vfan | i317 | ifan
0.0 | 9.0 | 0.0 | 4.999853428171583 | 0.045375751123209615 | 0.1890590123956069 | 1.445862072101164 | 0.06440658431967727 | 0.05783448288404403
0.0020000000000002655 | 9.0 | 0.0020000000000002655 | 4.999853428171622 | 0.04537578125191108 | 0.1890590166877728 | 1.445862075487538 | 0.06440658724959447 | 0.05783448301726621
0.006000000000000796 | 9.0 | 0.006000000000000796 | 4.999853428171629 | 0.04537580463824799 | 0.18905902062526783 | 1.4458620797851105 | 0.06440659009852112 | 0.0578344831934308
0.014000000000000123 | 9.0 | 0.014000000000000123 | 4.999853428171596 | 0.04537585041371444 | 0.18905902798618332 | 1.4458620876067774 | 0.06440659301480611 | 0.057834483504257024
0.030000000000000512 | 9.0 | 0.030000000000000512 | 4.999853428171532 | 0.04537594229024231 | 0.18905904249021666 | 1.4458621022361162 | 0.064406595101282 | 0.05783448408944475
0.0499999999999997 | 9.0 | 0.0499999999999997 | 4.999853428171463 | 0.045376057196346305 | 0.18905906057242142 | 1.4458621203194757 | 0.06440659595227727 | 0.057834484812781604
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

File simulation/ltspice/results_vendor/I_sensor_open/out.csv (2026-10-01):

sweep | vin | t | v5 | vref | vadj | vfan | i317 | ifan
0.0 | 9.0 | 0.0 | 4.999964508872743 | 0.28522899252493833 | 3.643904414681219 | 4.9005977045020455 | 0.21829935375688456 | 0.19602390817916862
0.0020000000000002655 | 9.0 | 0.0020000000000002655 | 4.999964508872745 | 0.2852289925252448 | 3.6439044146712605 | 4.9005977043991145 | 0.21829935368208603 | 0.1960239081759804
0.006000000000000796 | 9.0 | 0.006000000000000796 | 4.999964508872749 | 0.28522899252564593 | 3.6439044146889072 | 4.900597704567851 | 0.2182993538559946 | 0.19602390818271193
0.014000000000000123 | 9.0 | 0.014000000000000123 | 4.9999645088727425 | 0.285228992525806 | 3.6439044146823414 | 4.9005977045282645 | 0.21829935380306414 | 0.19602390818112012
0.030000000000000512 | 9.0 | 0.030000000000000512 | 4.999964508872743 | 0.2852289925256614 | 3.643904414684201 | 4.900597704533578 | 0.2182993538027719 | 0.19602390818215895
0.0499999999999997 | 9.0 | 0.0499999999999997 | 4.999964508872743 | 0.28522899252587014 | 3.64390441468315 | 4.900597704523148 | 0.21829935377835766 | 0.1960239081809357
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

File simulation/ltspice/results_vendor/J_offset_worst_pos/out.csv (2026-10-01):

sweep | vin | t | v5 | vref | vadj | vfan | i317 | ifan
0.0 | 9.0 | 0.0 | 4.99990087757411 | 0.2782249262238437 | 0.21232516463043472 | 1.4691273771579465 | 0.06544294793753902 | 0.05876509508629196
0.0020000000000002655 | 9.0 | 0.0020000000000002655 | 4.999900877574316 | 0.2782249263709656 | 0.21232516747249464 | 1.4691273793493456 | 0.06544294986319615 | 0.05876509517397055
0.006000000000000796 | 9.0 | 0.006000000000000796 | 4.999900877574449 | 0.2782249261438804 | 0.2123251684973849 | 1.4691273810155596 | 0.06544295069492721 | 0.05876509524063125
0.014000000000000123 | 9.0 | 0.014000000000000123 | 4.999900877574461 | 0.27822492622184697 | 0.2123251690606655 | 1.4691273818364265 | 0.06544294995926958 | 0.05876509527345125
0.030000000000000512 | 9.0 | 0.030000000000000512 | 4.999900877574468 | 0.27822492622921885 | 0.21232516985707858 | 1.4691273824998288 | 0.06544294879387397 | 0.058765095299985165
0.0499999999999997 | 9.0 | 0.0499999999999997 | 4.999900877574499 | 0.27822492622824496 | 0.21232517090153005 | 1.469127383426109 | 0.06544294853521523 | 0.05876509533703839
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

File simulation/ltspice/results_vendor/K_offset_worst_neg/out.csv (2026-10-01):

sweep | vin | t | v5 | vref | vadj | vfan | i317 | ifan
0.0 | 9.0 | 0.0 | 4.9999008621627405 | 0.2922250459356286 | 0.21447515948107831 | 1.4712772939057652 | 0.06553871694563596 | 0.05885109175537608
0.0020000000000002655 | 9.0 | 0.0020000000000002655 | 4.999900862162942 | 0.2922250460807786 | 0.21447516240860526 | 1.4712772961269227 | 0.06553871896901797 | 0.0588510918478683
0.006000000000000796 | 9.0 | 0.006000000000000796 | 4.999900862163062 | 0.2922250458549789 | 0.21447516351206775 | 1.4712772979549176 | 0.06553871992408311 | 0.05885109192078107
0.014000000000000123 | 9.0 | 0.014000000000000123 | 4.999900862163043 | 0.2922250459325302 | 0.21447516395742502 | 1.471277298709114 | 0.06553871898581454 | 0.05885109194663531
0.030000000000000512 | 9.0 | 0.030000000000000512 | 4.999900862162988 | 0.2922250459393357 | 0.2144751643221246 | 1.4712772988409353 | 0.06553871752135798 | 0.05885109195364561
0.0499999999999997 | 9.0 | 0.0499999999999997 | 4.9999008621629395 | 0.29222504593903603 | 0.21447516496788768 | 1.4712772993761039 | 0.06553871727204064 | 0.05885109197505997
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

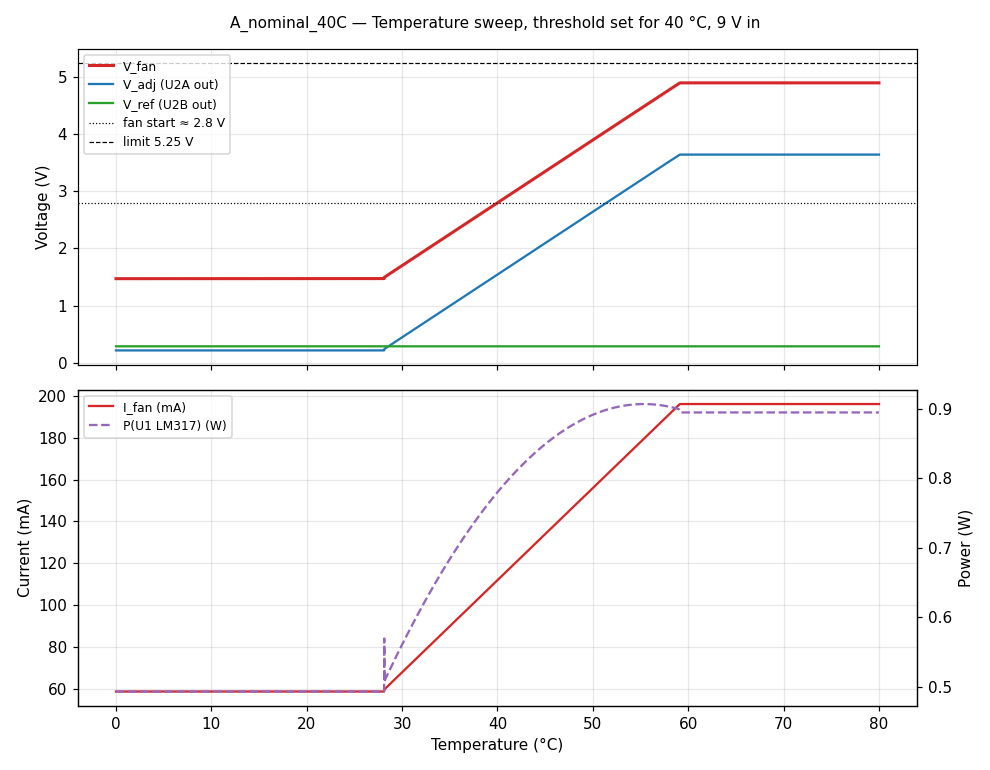
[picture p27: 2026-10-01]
simulation/ltspice/results_vendor/A_nominal_40C/plot.png

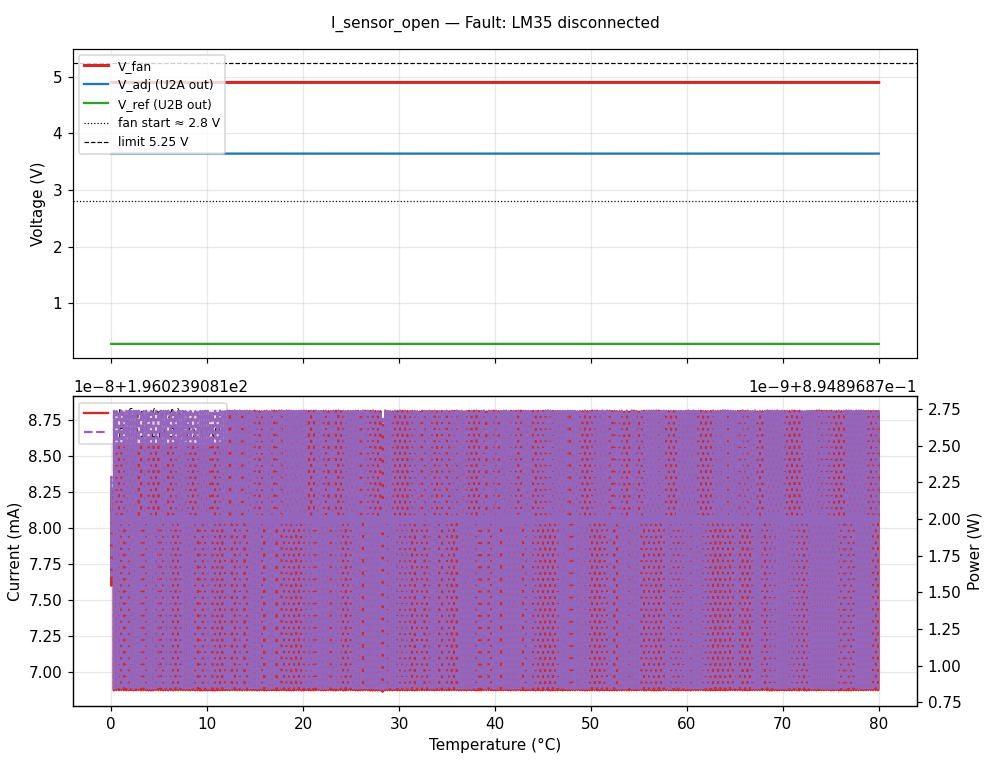
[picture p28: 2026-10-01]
simulation/ltspice/results_vendor/I_sensor_open/plot.png

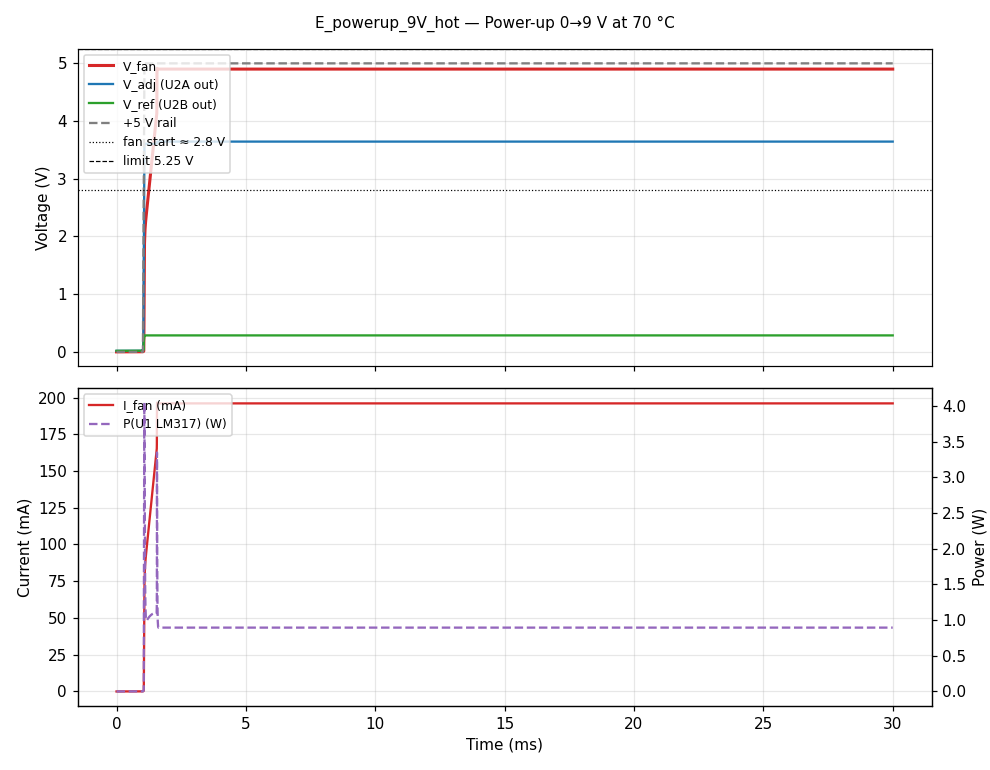
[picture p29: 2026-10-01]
simulation/ltspice/results_vendor/E_powerup_9V_hot/plot.png

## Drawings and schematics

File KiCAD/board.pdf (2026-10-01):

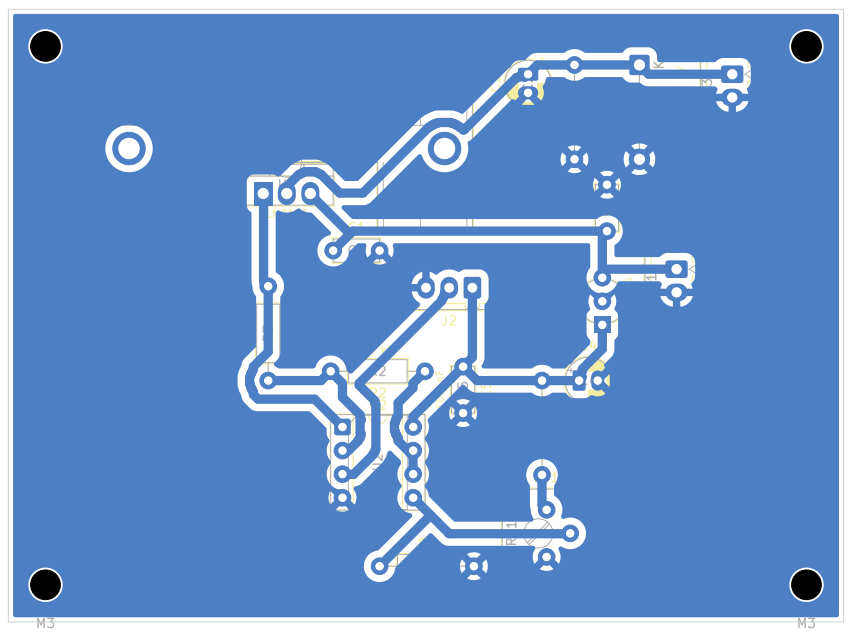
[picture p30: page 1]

ZK-4KX fan controller rev 1.1

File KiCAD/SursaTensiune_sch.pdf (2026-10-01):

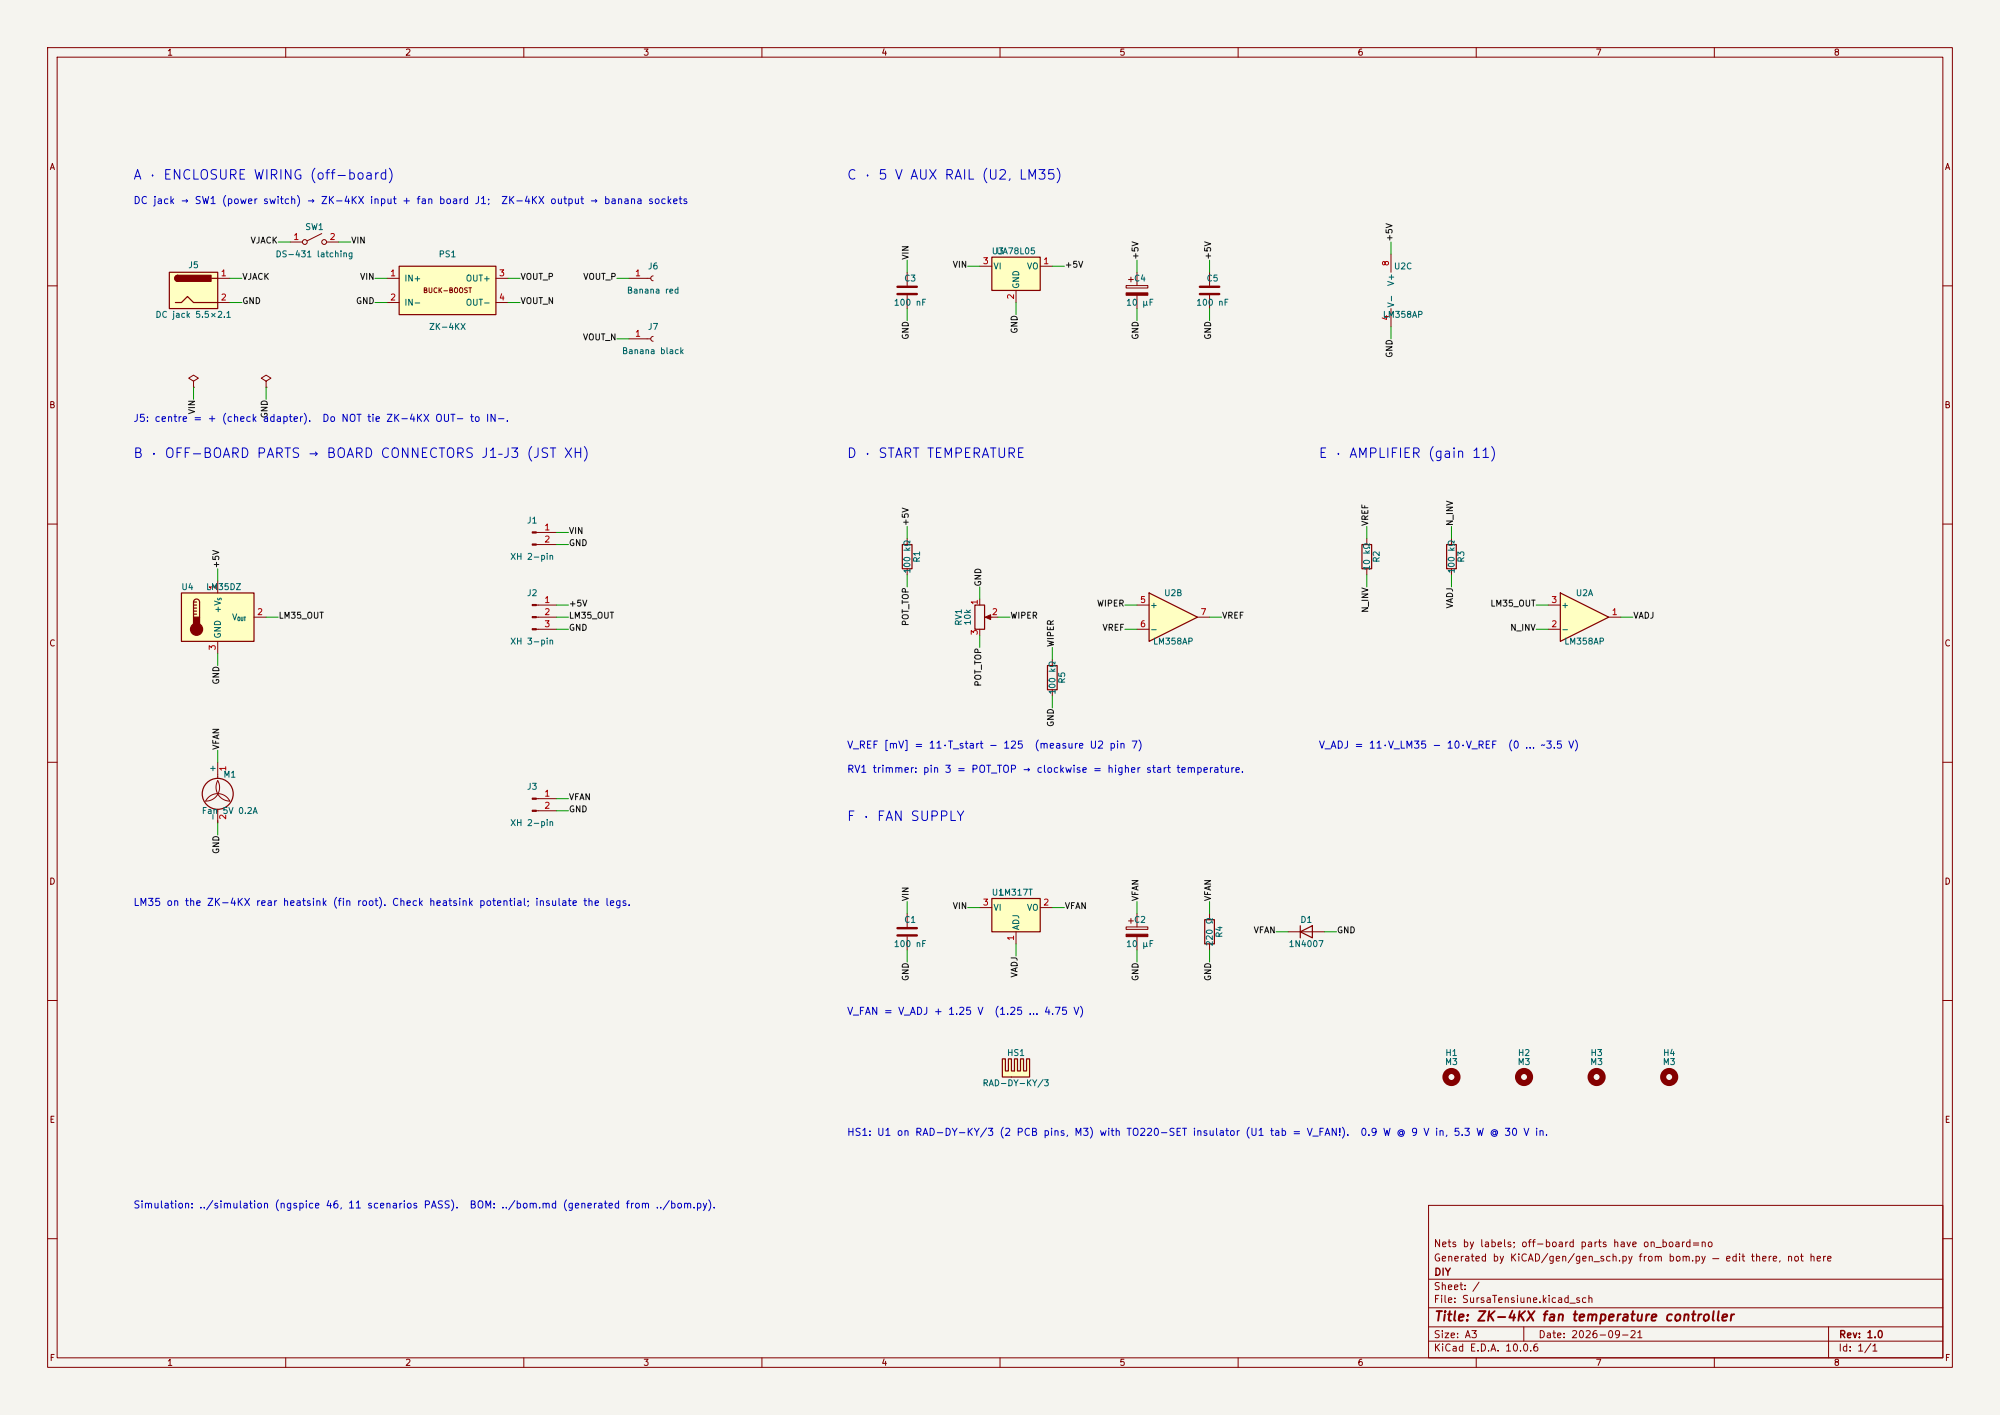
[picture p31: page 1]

GND GND VIN VIN +5V GND

DC jack → SW1 (power switch) → ZK-4KX input + fan board J1; ZK-4KX output → banana sockets

J5: centre = + (check adapter). Do NOT tie ZK-4KX OUT− to IN−.

RV1 trimmer: pin 3 = POT_TOP → clockwise = higher start temperature.

LM35 on the ZK-4KX rear heatsink (fin root). Check heatsink potential; insulate the legs.

HS1: U1 on RAD-DY-KY/3 (2 PCB pins, M3) with TO220-SET insulator (U1 tab = V_FAN!). 0.9 W @ 9 V in, 5.3 W @ 30 V in.

Simulation: ../simulation (ngspice 46, 11 scenarios PASS). BOM: ../bom.md (generated from ../bom.py).

Nets by labels; off-board parts have on_board=no
Generated by KiCAD/gen/gen_sch.py from bom.py — edit there, not here
DIY
Sheet: /
File: SursaTensiune.kicad_sch
Title: ZK-4KX fan temperature controller

Size: A3 | Rev: 1.0 | F Date: 2026-09-21
KiCad E.D.A. 10.0.6 | Id: 1/1

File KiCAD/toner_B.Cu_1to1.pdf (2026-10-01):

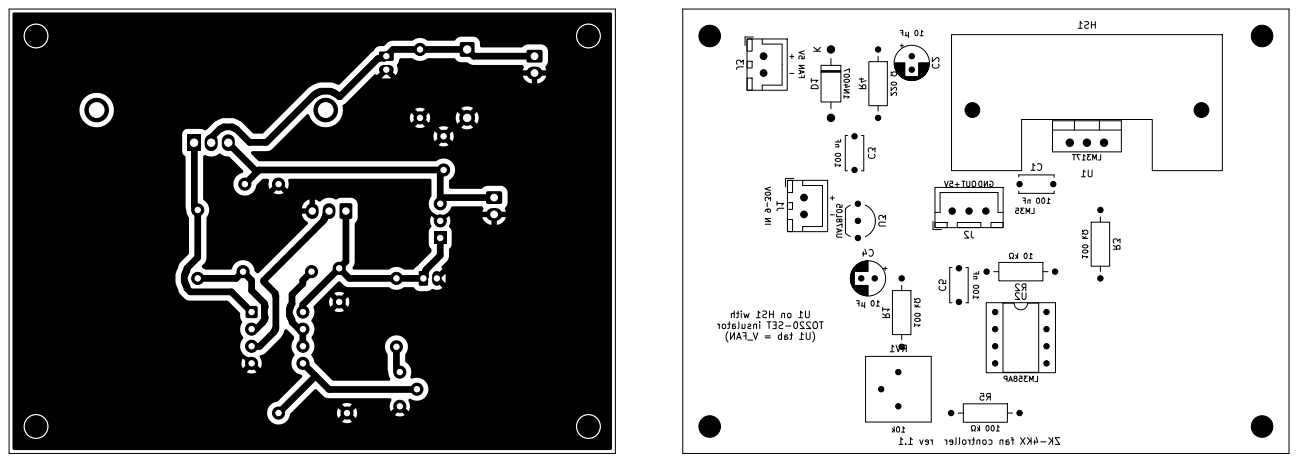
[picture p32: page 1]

10k C3 100 nF J1 IN 9-30V J3 FAN 5V C5 100 nF U2

1.1 rev controller fan ZK-4KX with HS1 on U1

# 100 kΩ R4 220 Ω C2

# 10 µF R2

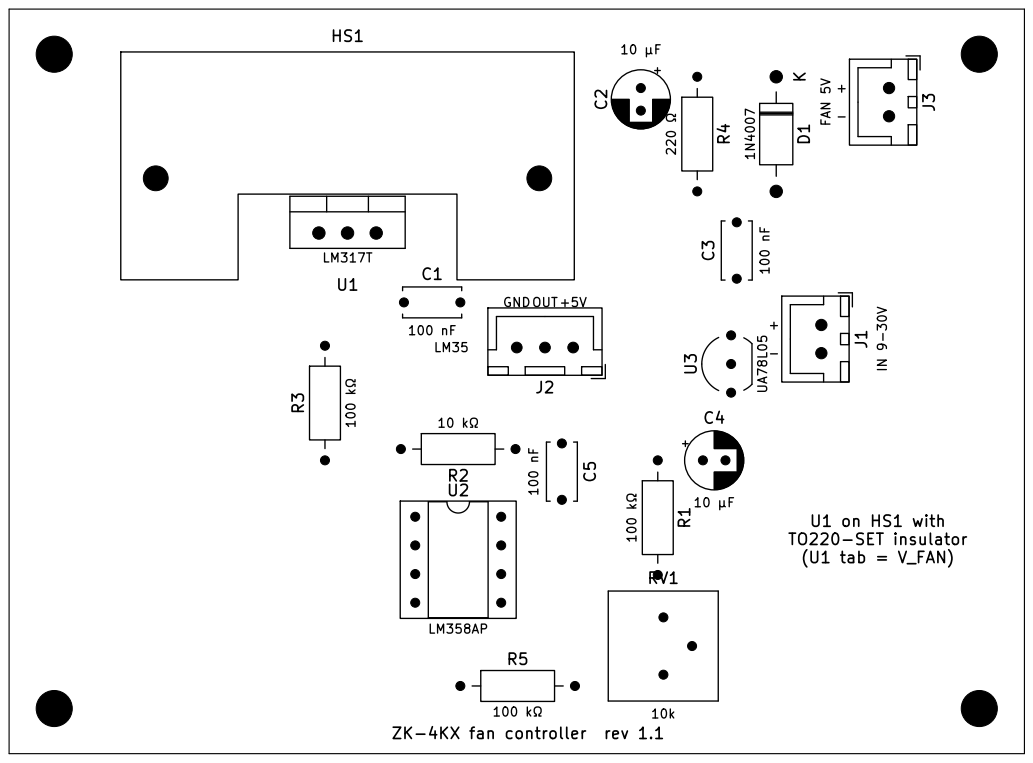
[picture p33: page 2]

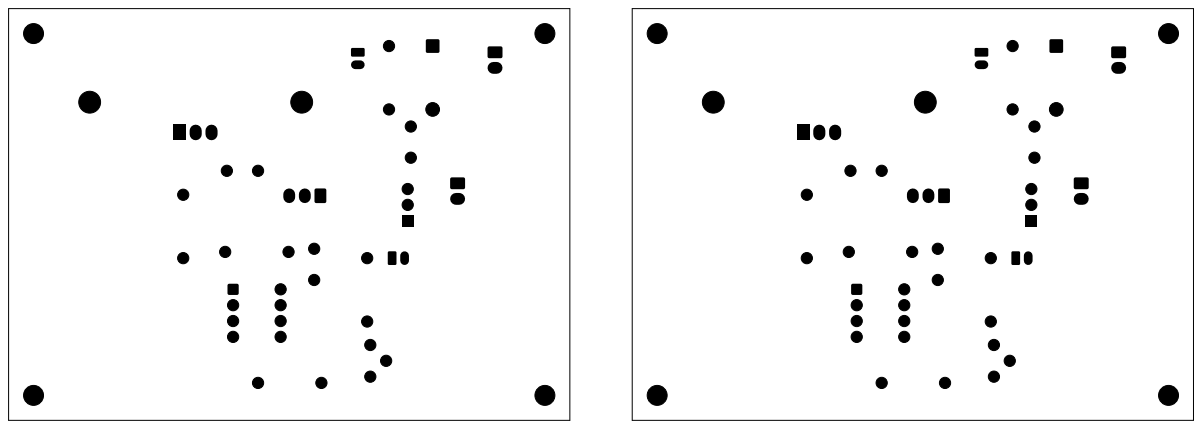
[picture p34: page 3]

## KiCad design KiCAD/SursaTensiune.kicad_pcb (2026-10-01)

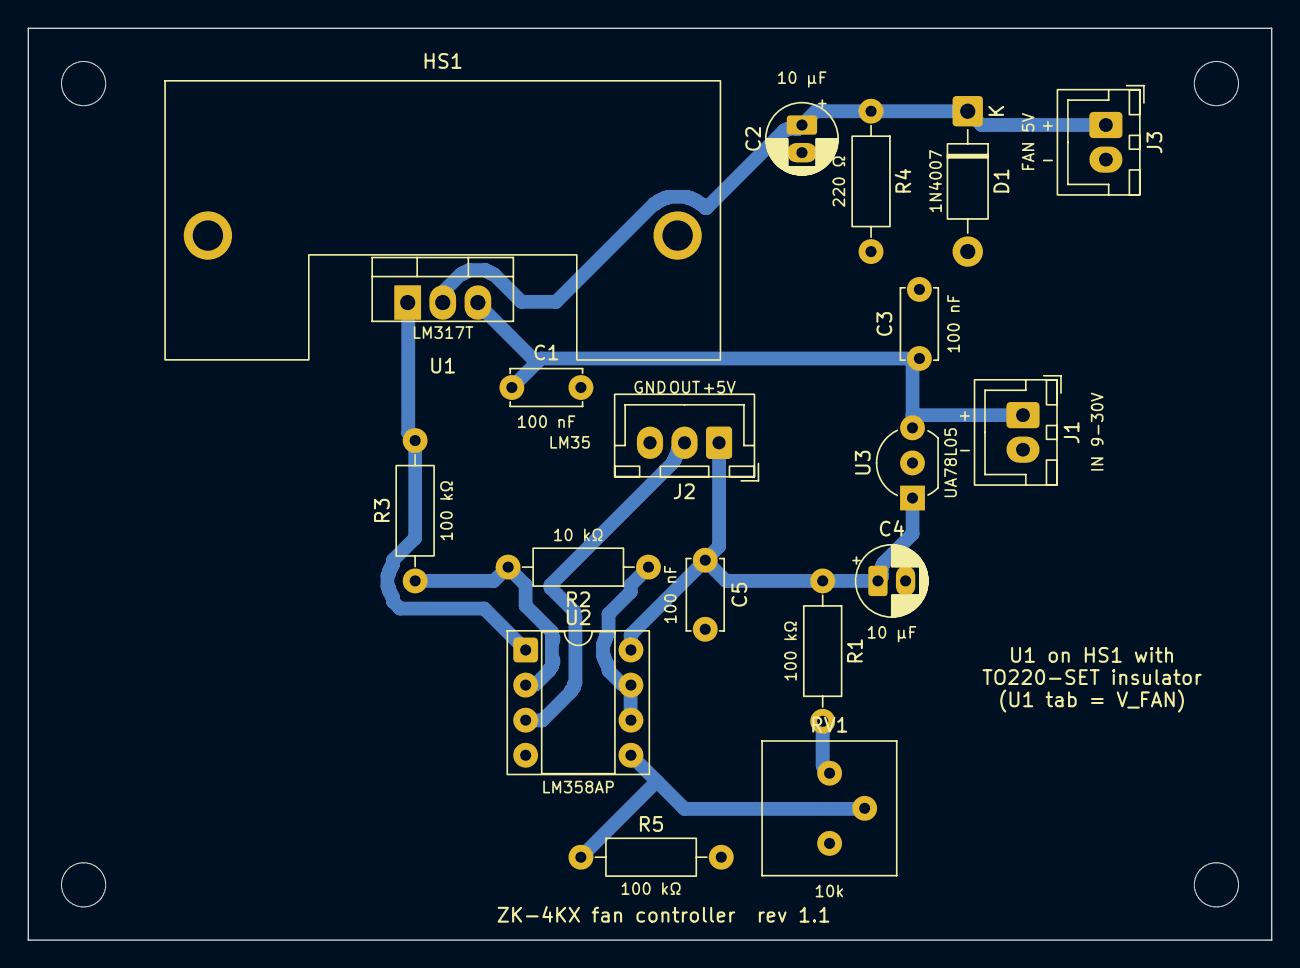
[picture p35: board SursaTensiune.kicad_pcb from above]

Board: 2 copper layers, 90.0 x 66.0 mm, 23 parts (0 on the bottom side), 10 nets.

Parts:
C1, C3, C5: 100 nF; C_Disc_D5.0mm_W2.5mm_P5.00mm
C2, C4: 10 µF; CP_Radial_D5.0mm_P2.00mm
D1: 1N4007; D_DO-41_SOD81_P10.16mm_Horizontal
H1, H2, H3, H4: M3; MountingHole_3.2mm_M3
HS1: RAD-DY-KY/3; Heatsink_Stonecold_RAD-DY-KY-3_40x20mm_P34mm
J1: IN 9-30V; JST_XH_B2B-XH-A_1x02_P2.50mm_Vertical
J2: LM35; JST_XH_B3B-XH-A_1x03_P2.50mm_Vertical
J3: FAN 5V; JST_XH_B2B-XH-A_1x02_P2.50mm_Vertical
R1, R3, R5: 100 kΩ; R_Axial_DIN0207_L6.3mm_D2.5mm_P10.16mm_Horizontal
R2: 10 kΩ; R_Axial_DIN0207_L6.3mm_D2.5mm_P10.16mm_Horizontal
R4: 220 Ω; R_Axial_DIN0207_L6.3mm_D2.5mm_P10.16mm_Horizontal
RV1: 10k; Potentiometer_Bourns_3386P_Vertical
U1: LM317T; TO-220-3_Vertical
U2: LM358AP; DIP-8_W7.62mm_Socket
U3: UA78L05; TO-92_Inline_Wide

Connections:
/+5V: C4.1, C5.1, J2.1, R1.1, U2.8, U3.1
/GND: C1.2, C2.2, C3.2, C4.2, C5.2, D1.2, J1.2, J2.3, J3.2, R4.2, R5.2, RV1.1, U2.4, U3.2
/LM35_OUT: J2.2, U2.3
/N_INV: R2.2, R3.1, U2.2
/POT_TOP: R1.2, RV1.3
/VADJ: R3.2, U1.1, U2.1
/VFAN: C2.1, D1.1, J3.1, R4.1, U1.2
/VIN: C1.1, C3.1, J1.1, U1.3, U3.3
/VREF: R2.1, U2.6, U2.7
/WIPER: R5.1, RV1.2, U2.5

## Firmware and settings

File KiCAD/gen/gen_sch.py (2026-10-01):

"""Generate SursaTensiune.kicad_sch from stock KiCad symbols + bom.py.

Every pin gets a short wire stub ending in a net label (no long wires), so the
netlist is defined entirely by the NET tables below. Values, descriptions and
inventory IDs come from bom.py; symbols/footprints are assigned here.

Run:  python gen_sch.py   (then kicad-cli ERC / netlist check, see check.py)
"""
import sys
import uuid
from pathlib import Path

from sexp import Q, dump, find, first, lib_symbol, outward, pins

ROOT = Path(__file__).resolve().parents[2]
PRJ = ROOT / "KiCAD"
sys.path.insert(0, str(ROOT))
from bom import BOM  # noqa: E402

NAME = "SursaTensiune"
LOCAL_LIB = PRJ / f"{NAME}.kicad_sym"
ROOT_UUID = "5a000000-0000-4000-8000-000000000001"
STUB = 2.54

BOMREF = {r: item for item in BOM for r in item["refs"]}

FP = {
    "R": "Resistor_THT:R_Axial_DIN0207_L6.3mm_D2.5mm_P10.16mm_Horizontal",
    "C": "Capacitor_THT:C_Disc_D5.0mm_W2.5mm_P5.00mm",
    "CP": "Capacitor_THT:CP_Radial_D5.0mm_P2.00mm",
    "XH2": "Connector_JST:JST_XH_B2B-XH-A_1x02_P2.50mm_Vertical",
    "XH3": "Connector_JST:JST_XH_B3B-XH-A_1x03_P2.50mm_Vertical",
}

# ── Parts: (ref, lib_id, unit, (x, y), {pin: net}, footprint | None=off-board) ──
# Nets: VJACK VIN GND +5V VREF N_INV VADJ VFAN LM35_OUT POT_TOP WIPER VOUT_P VOUT_N
P = []


def part(ref, lib_id, at, nets, fp=None, unit=1, value=None, bom=True, sim=True):
    P.append(dict(ref=ref, lib_id=lib_id, unit=unit, at=at, nets=nets, fp=fp,
                  value=value, bom=bom))


# Block A — enclosure wiring (off-board)
part("J5", "Connector:Barrel_Jack", (40.64, 60.96), {"1": "VJACK", "2": "GND"})
part("SW1", "Switch:SW_SPST", (66.04, 50.8), {"1": "VJACK", "2": "VIN"})
part("PS1", f"{NAME}:ZK-4KX", (93.98, 60.96), {"1": "VIN", "2": "GND", "3": "VOUT_P", "4": "VOUT_N"})
part("J6", "Connector:Conn_01x01_Socket", (137.16, 58.42), {"1": "VOUT_P"})
part("J7", "Connector:Conn_01x01_Socket", (137.16, 71.12), {"1": "VOUT_N"})
part("#FLG01", "power:PWR_FLAG", (40.64, 81.28), {"1": "VIN"}, bom=False, value="PWR_FLAG")
part("#FLG02", "power:PWR_FLAG", (55.88, 81.28), {"1": "GND"}, bom=False, value="PWR_FLAG")

# Block B — board connectors + the off-board parts plugged into them
part("J1", "Connector:Conn_01x02_Pin", (111.76, 111.76), {"1": "VIN", "2": "GND"}, FP["XH2"])
part("J2", "Connector:Conn_01x03_Pin", (111.76, 129.54), {"1": "+5V", "2": "LM35_OUT", "3": "GND"}, FP["XH3"])
part("J3", "Connector:Conn_01x02_Pin", (111.76, 167.64), {"1": "VFAN", "2": "GND"}, FP["XH2"])
part("U4", "Sensor_Temperature:LM35-LP", (45.72, 129.54), {"1": "+5V", "2": "LM35_OUT", "3": "GND"})
part("M1", "Motor:Fan", (45.72, 167.64), {"1": "VFAN", "2": "GND"})

# Block C — 5 V aux rail
part("C3", "Device:C", (190.5, 60.96), {"1": "VIN", "2": "GND"}, FP["C"])
part("U3", "Regulator_Linear:L78L05_TO92", (213.36, 55.88), {"3": "VIN", "1": "+5V", "2": "GND"},
     "Package_TO_SOT_THT:TO-92_Inline_Wide")
part("C4", "Device:C_Polarized", (238.76, 60.96), {"1": "+5V", "2": "GND"}, FP["CP"])
part("C5", "Device:C", (254.0, 60.96), {"1": "+5V", "2": "GND"}, FP["C"])
part("U2", "Amplifier_Operational:LM358", (294.64, 60.96), {"8": "+5V", "4": "GND"},
     "Package_DIP:DIP-8_W7.62mm_Socket", unit=3)

# Block D — start temperature (threshold) + U2B buffer
part("R1", "Device:R", (190.5, 116.84), {"1": "+5V", "2": "POT_TOP"}, FP["R"])
part("RV1", "Device:R_Potentiometer", (205.74, 129.54), {"3": "POT_TOP", "2": "WIPER", "1": "GND"},
     "Potentiometer_THT:Potentiometer_Bourns_3386P_Vertical")
part("R5", "Device:R", (220.98, 142.24), {"1": "WIPER", "2": "GND"}, FP["R"])
part("U2", "Amplifier_Operational:LM358", (246.38, 129.54), {"5": "WIPER", "6": "VREF", "7": "VREF"},
     "Package_DIP:DIP-8_W7.62mm_Socket", unit=2)

# Block E — amplifier U2A (gain 11)
part("R2", "Device:R", (287.02, 116.84), {"1": "VREF", "2": "N_INV"}, FP["R"])
part("R3", "Device:R", (304.8, 116.84), {"1": "N_INV", "2": "VADJ"}, FP["R"])
part("U2", "Amplifier_Operational:LM358", (332.74, 129.54), {"3": "LM35_OUT", "2": "N_INV", "1": "VADJ"},
     "Package_DIP:DIP-8_W7.62mm_Socket", unit=1)

# Block F — fan supply
part("C1", "Device:C", (190.5, 195.58), {"1": "VIN", "2": "GND"}, FP["C"])
part("U1", "Regulator_Linear:LM317_TO-220", (213.36, 190.5), {"3": "VIN", "1": "VADJ", "2": "VFAN"},
     "Package_TO_SOT_THT:TO-220-3_Vertical")
part("C2", "Device:C_Polarized", (238.76, 195.58), {"1": "VFAN", "2": "GND"}, FP["CP"])
part("R4", "Device:R", (254.0, 195.58), {"1": "VFAN", "2": "GND"}, FP["R"])
part("D1", "Diode:1N4007", (274.32, 195.58), {"1": "VFAN", "2": "GND"},
     "Diode_THT:D_DO-41_SOD81_P10.16mm_Horizontal")

# Mechanical
part("HS1", "Mechanical:Heatsink", (213.36, 226.06), {}, f"{NAME}:Heatsink_Stonecold_RAD-DY-KY-3_40x20mm_P34mm")
for i, x in enumerate((304.8, 320.04, 335.28, 350.52), 1):
    part(f"H{i}", "Mechanical:MountingHole", (x, 226.06), {}, "MountingHole:MountingHole_3.2mm_M3", bom=False)

TEXTS = [
    ((27.94, 38.1), "A · ENCLOSURE WIRING (off-board)", 2.0),
    ((27.94, 43.18), "DC jack → SW1 (power switch) → ZK-4KX input + fan board J1;  ZK-4KX output → banana sockets", 1.5),
    ((27.94, 96.52), "B · OFF-BOARD PARTS → BOARD CONNECTORS J1–J3 (JST XH)", 2.0),
    ((177.8, 38.1), "C · 5 V AUX RAIL (U2, LM35)", 2.0),
    ((177.8, 96.52), "D · START TEMPERATURE", 2.0),
    ((177.8, 157.48), "V_REF [mV] = 11·T_start − 155  (measure U2 pin 7)", 1.5),
    ((276.86, 96.52), "E · AMPLIFIER (gain 11)", 2.0),
    ((276.86, 157.48), "V_ADJ = 11·V_LM35 − 10·V_REF  (0 … ~3.5 V)", 1.5),
    ((177.8, 172.72), "F · FAN SUPPLY", 2.0),
    ((177.8, 213.36), "V_FAN = V_ADJ + 1.25 V  (1.25 … 4.75 V)", 1.5),
    ((27.94, 88.9), "J5: centre = + (check adapter).  Do NOT tie ZK-4KX OUT− to IN−.", 1.5),
    ((27.94, 190.5), "LM35 on the ZK-4KX rear heatsink (fin root). Check heatsink potential; insulate the legs.", 1.5),
    ((177.8, 162.56), "RV1 trimmer: pin 3 = POT_TOP → clockwise = higher start temperature.", 1.5),
    ((177.8, 238.76), "HS1: U1 on RAD-DY-KY/3 (2 PCB pins, M3) with TO220-SET insulator (U1 tab = V_FAN!).  "
                      "0.9 W @ 9 V in, 5.3 W @ 30 V in.", 1.5),
    ((27.94, 254.0), "Simulation: ../simulation (ngspice 46, 11 scenarios PASS).  BOM: ../bom.md "
                     "(generated from ../bom.py).", 1.5),
]


# ── Helpers ───────────────────────────────────────────────────────────────────
def U():
    return Q(str(uuid.uuid4()))


def eff(size=1.27, justify=None, hide=False):
    e = ["effects", ["font", ["size", size, size]]]
    if justify:
        e.append(["justify", *justify.split()])
    return e


def prop(name, value, at, hide=False):
    p = ["property", Q(name), Q(value), ["at", *at], ["show_name", "no"], ["do_not_autoplace", "no"]]
    if hide:
        p.append(["hide", "yes"])
    p.append(eff())
    return p


def r2(v):
    return round(v, 2)
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

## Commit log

2026-10-01 ZK-4KX power supply with temperature-controlled fan
    KiCad project, Gerbers, 3D-printable enclosure and solder-mask jig, SPICE simulations, build guide and photos.
    [DC_jack_5.5x2.1_PCB.step, DC_jack_5.5x2.1_panel_10A.step, DS-431_square_push_button_red.step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]
2026-10-01 Credits: GrabCAD sources for the fan and panel DC jack models
2026-10-01 Remove unused PCB-mount DC jack model
    [DC_jack_5.5x2.1_PCB.step]
2026-10-03 Build guide + BOM: printed standoffs, fan screws, lid magnets (match the enclosure)
2026-10-03 Enclosure: 3MF files in print orientation (base floor-down, cover flipped)
    [Enclosure_base.3mf, Enclosure_cover.3mf]
2026-10-03 Enclosure: Bambu Studio project 3MF (A1, 0.20mm Standard, PLA Basic, two plates)
    [Enclosure_A1_project.3mf]
2026-10-03 Enclosure project 3MF: real A1 bed (256 mm) and presets, cover centred on plate 2
    [Enclosure_A1_project.3mf]
2026-10-03 PCBWay assembly BOM (their xlsx template), generated from bom.py
    [SursaTensiune_BOM_PCBWay.xlsx]
